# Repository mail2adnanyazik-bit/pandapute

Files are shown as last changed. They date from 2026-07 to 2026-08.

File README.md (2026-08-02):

# Pandapute - a mini computer built from scratch

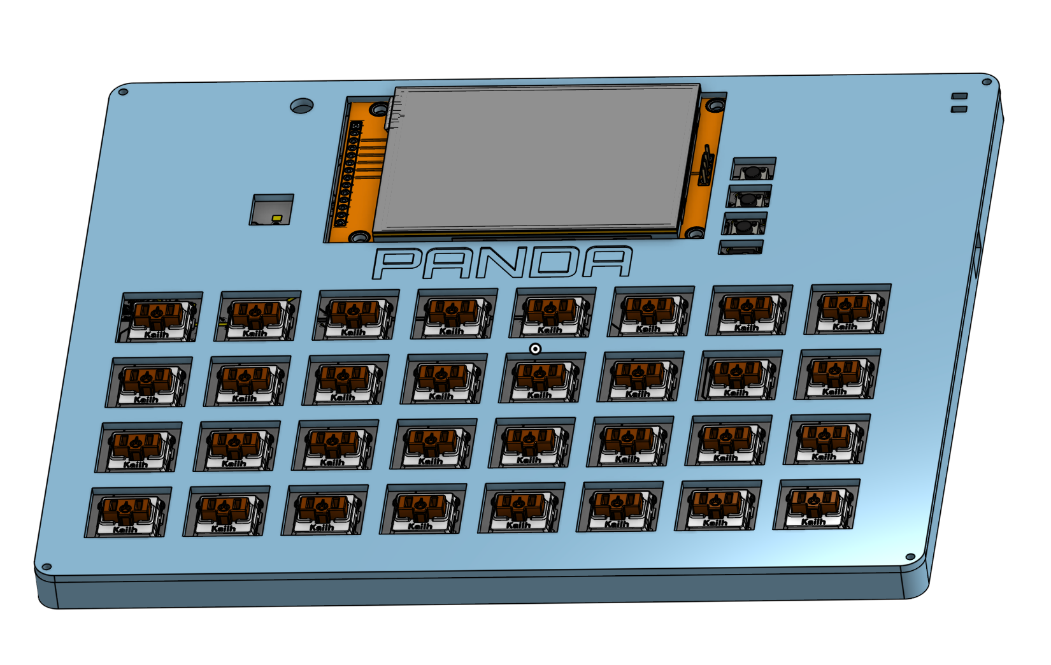
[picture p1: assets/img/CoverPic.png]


Before you keep reading and find out more about my kickass project, first I want to give credit and a massive thanks to @zsharpminor, or Udo - He's my first friend on Hack Club, a reviewer, and all-around great guy who helped me with this project along every step of the way.
This project would not have been possible without him, so <3 to him :D

## The Inspiration

So, one day I was working on my Split Keyboard project at my makespace, and I saw a friend of mine using a cardputer adv (which is a small, portable esp-based computer - see pic), and was curious.
I asked him what it was, and he showed me, and I gotta say, I was skeptical at first, but then I was blown away - I just had one complaint when I saw the thing :
the keyboard. You see, the original cardputer uses this tiny ass 56-key keyboard, which is 1) too many keys in my opinion, and 2) extremely hard to type on.

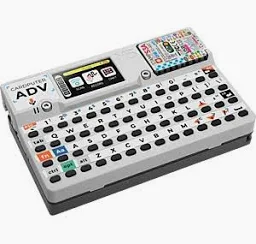
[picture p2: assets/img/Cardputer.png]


So, I decided to make my own, and get funding from Outpost.

## The Features

So, the Pandapute features every single feature the Cardputer has + more !

It has :

- The best ESP32 chip that has wifi and bluetooth capabilities (ESP32-S3-WROOM-1-N16R8)
- an actual **extremely** low profile, compact, built in mechanical 32-key keyboard
- an Audio Jack
- A LiPo battery that will last ages
- a built in speaker
- a microphone
- exposed I2C, GPIO, Power, etc. Pins so you can connect external modules or breakout boards, like a secondary display
- A USB-C port for **both** flashing **and** charging
- a tilt sensor (to do cool stuff)
- a 2.8" display (around twice as big as the cardputer)

## The Build

The Cardputer is built from scratch by me, Panda

It features an entirely custom

### Schematic

#### Power

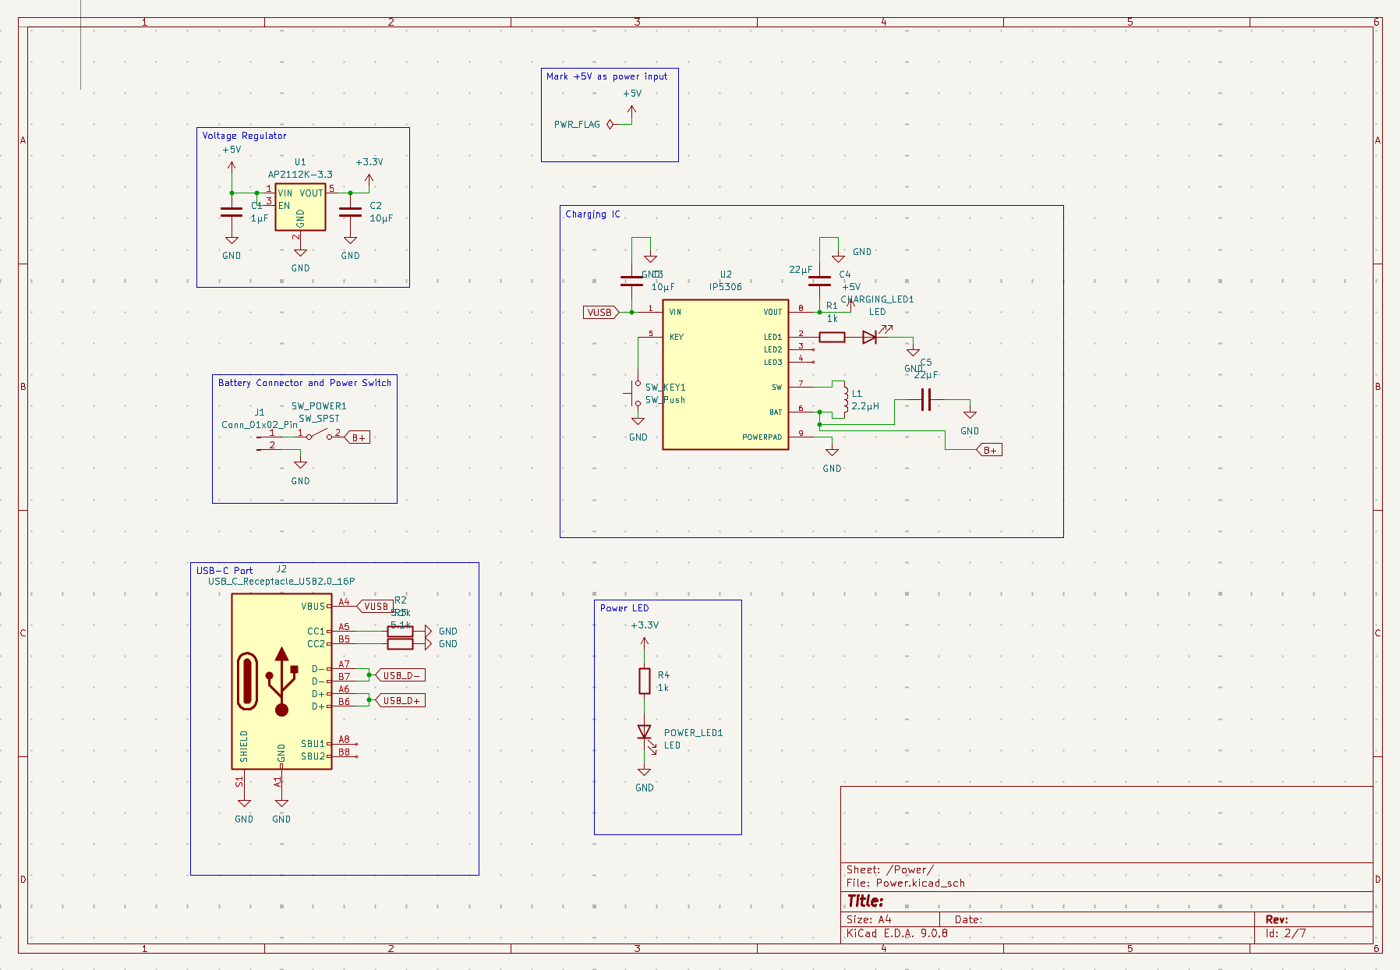
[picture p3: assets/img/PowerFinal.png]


#### ESP



#### Audio

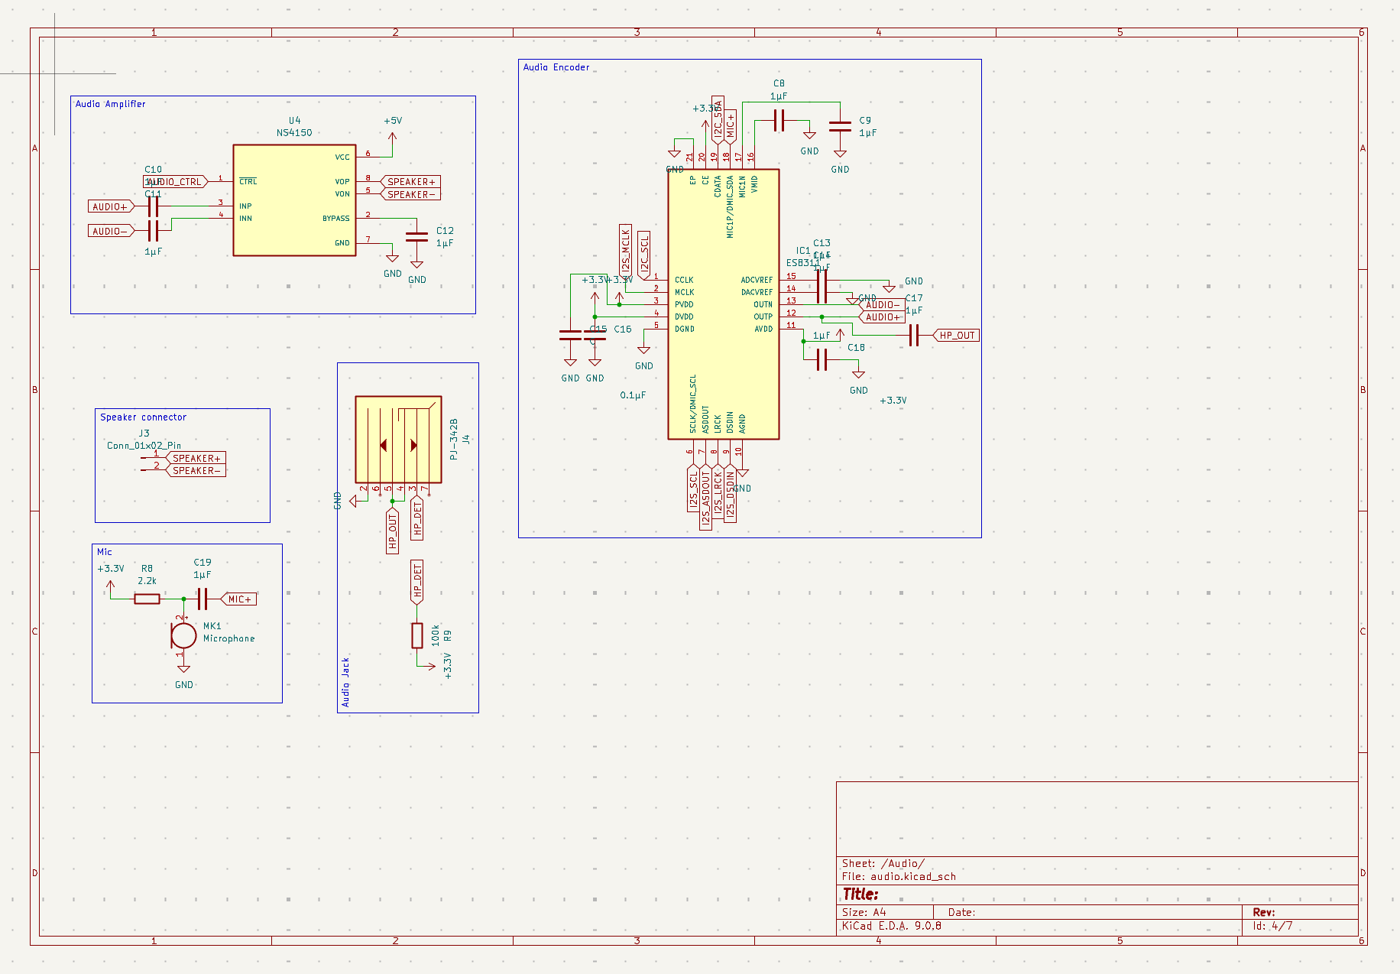
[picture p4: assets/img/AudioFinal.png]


#### Display

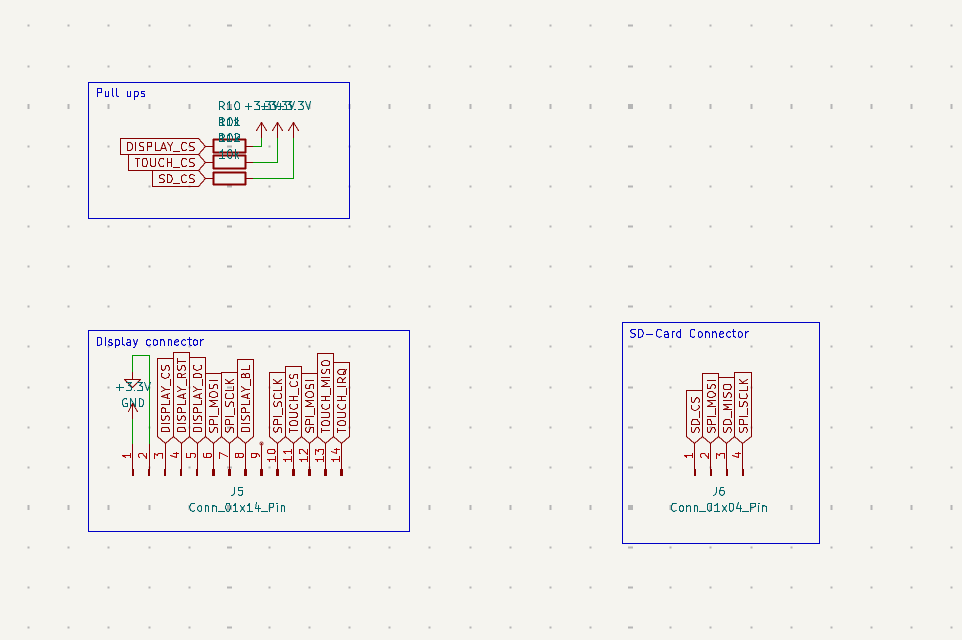
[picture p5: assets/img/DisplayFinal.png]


#### Keyboard

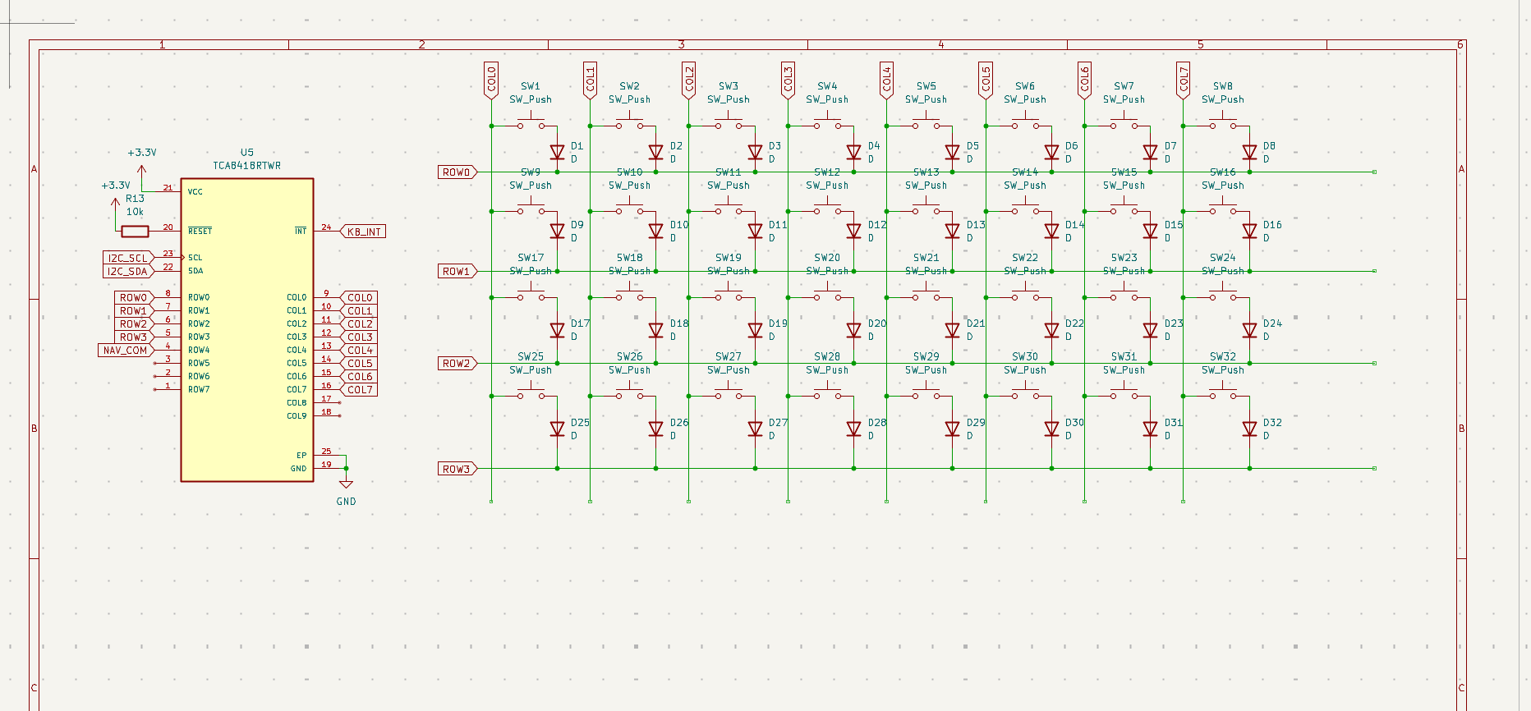
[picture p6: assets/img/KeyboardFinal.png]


#### Peripherals

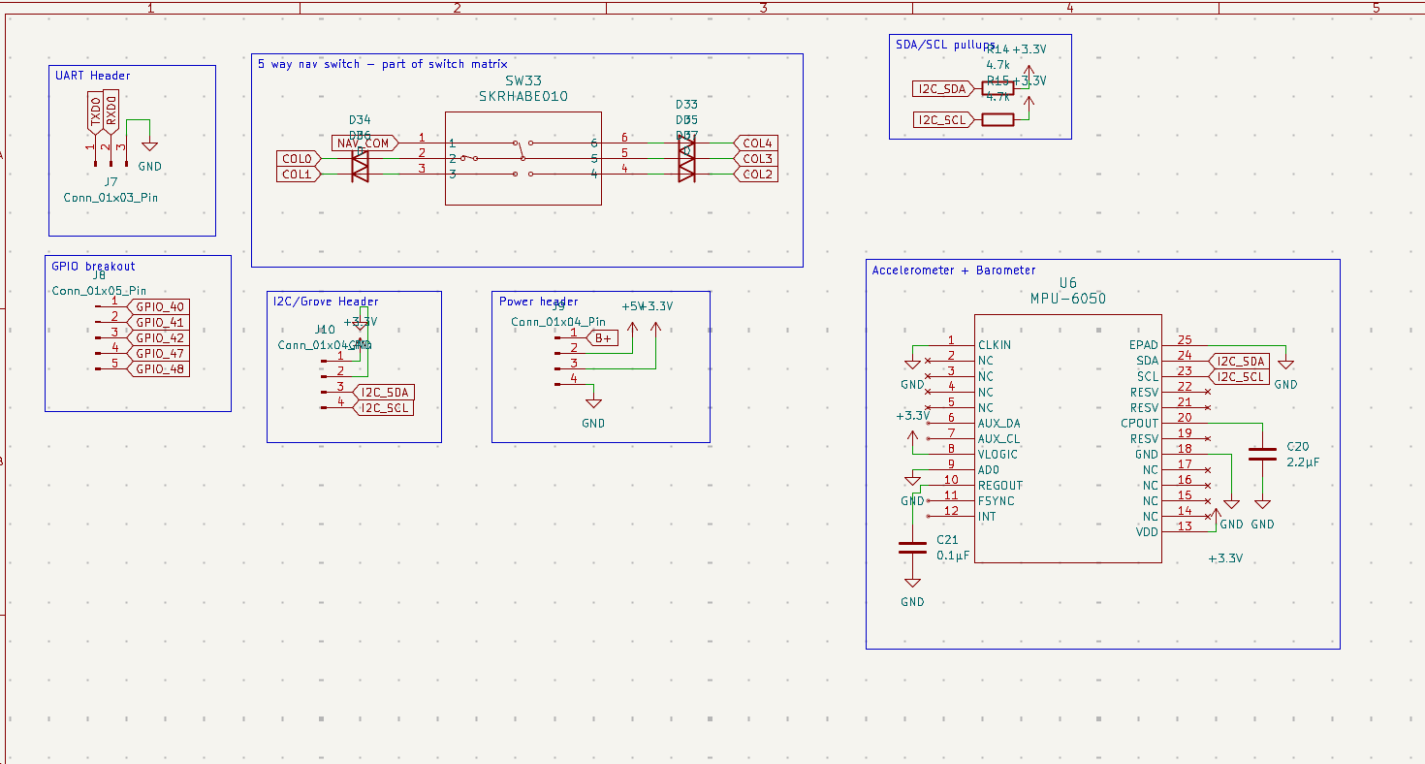
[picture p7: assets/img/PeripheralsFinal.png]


and

### PCB

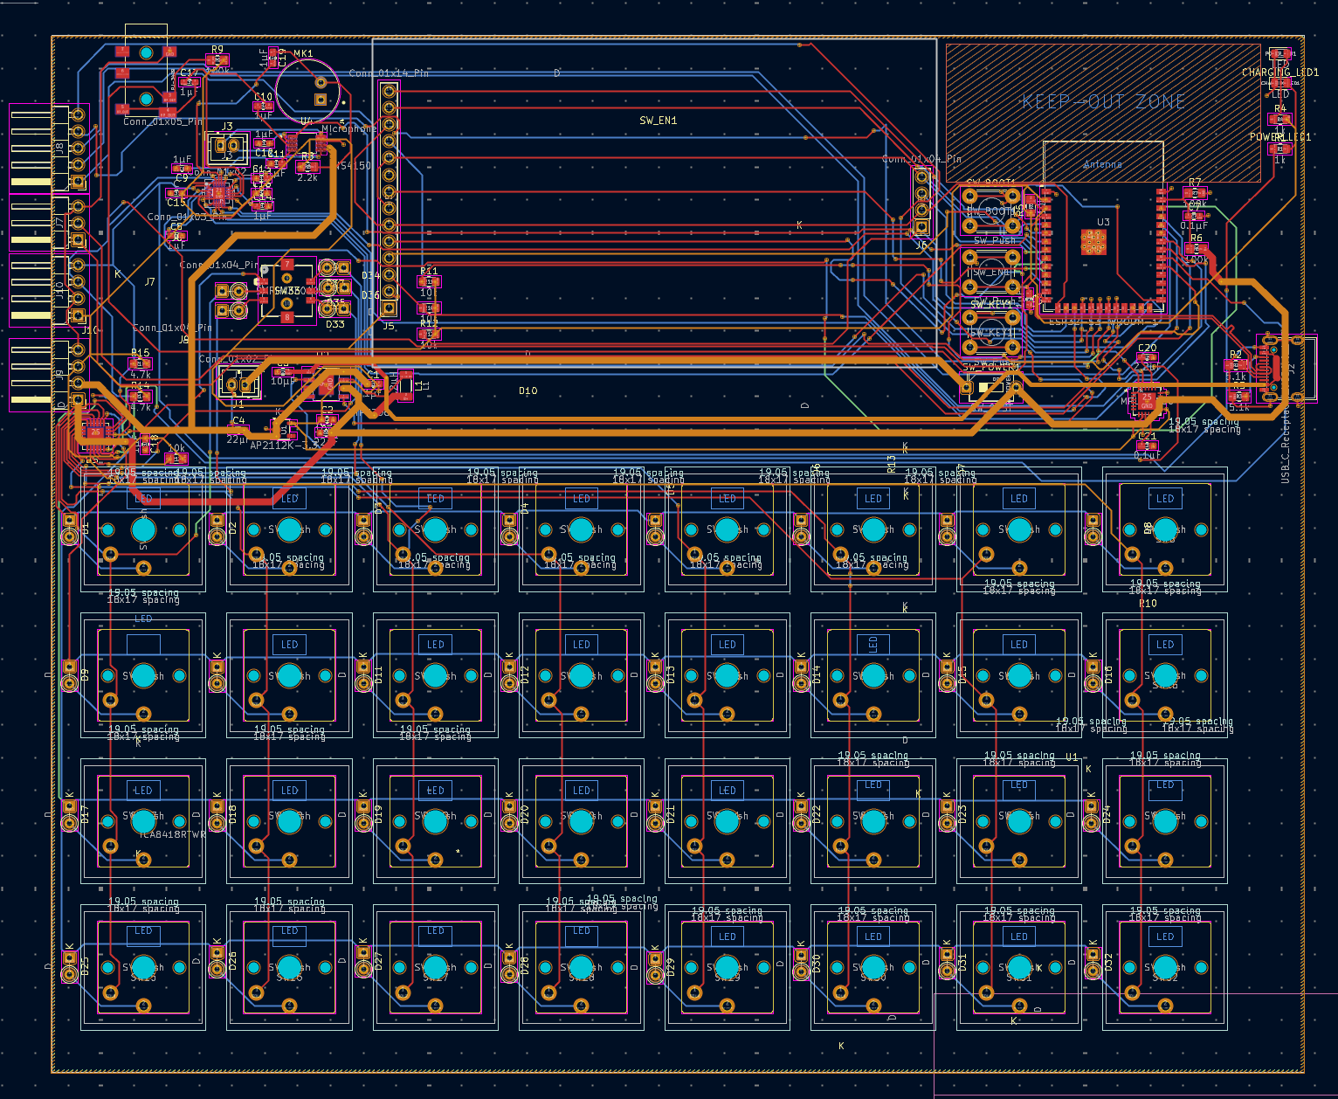
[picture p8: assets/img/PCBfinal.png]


to visualize how this will look in real life, here are a few pics ! I only added the important components that you'll actually see, not the encoder chips and stuff :

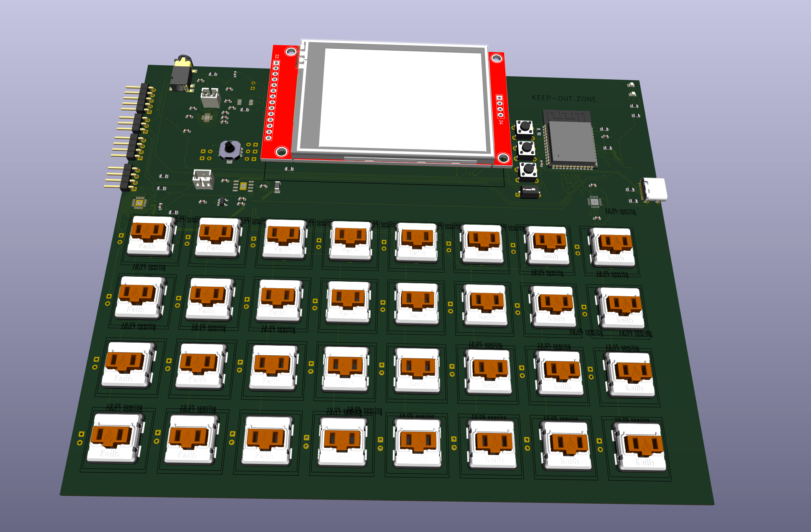
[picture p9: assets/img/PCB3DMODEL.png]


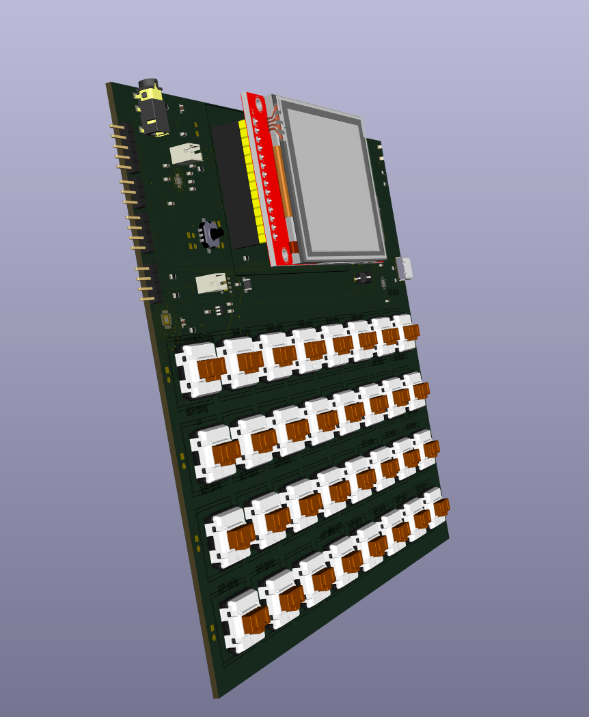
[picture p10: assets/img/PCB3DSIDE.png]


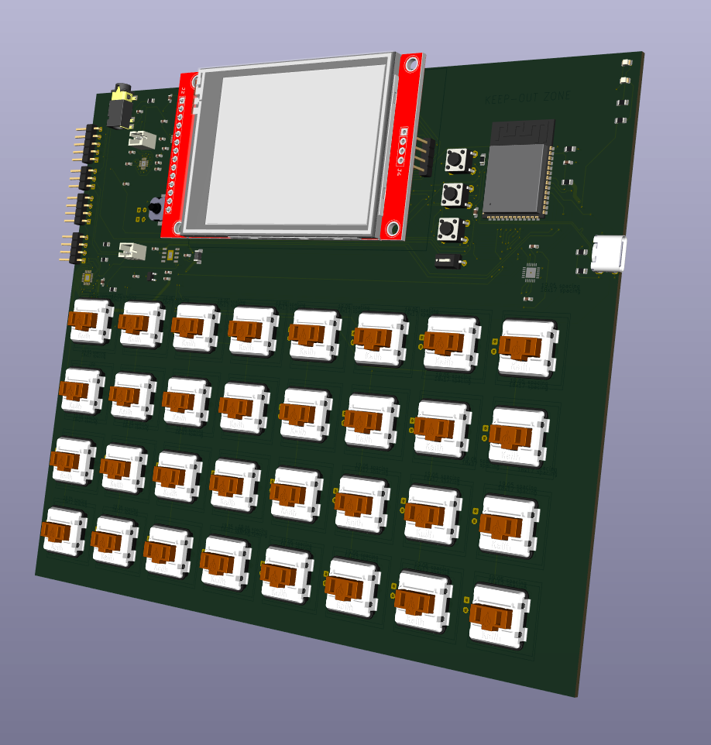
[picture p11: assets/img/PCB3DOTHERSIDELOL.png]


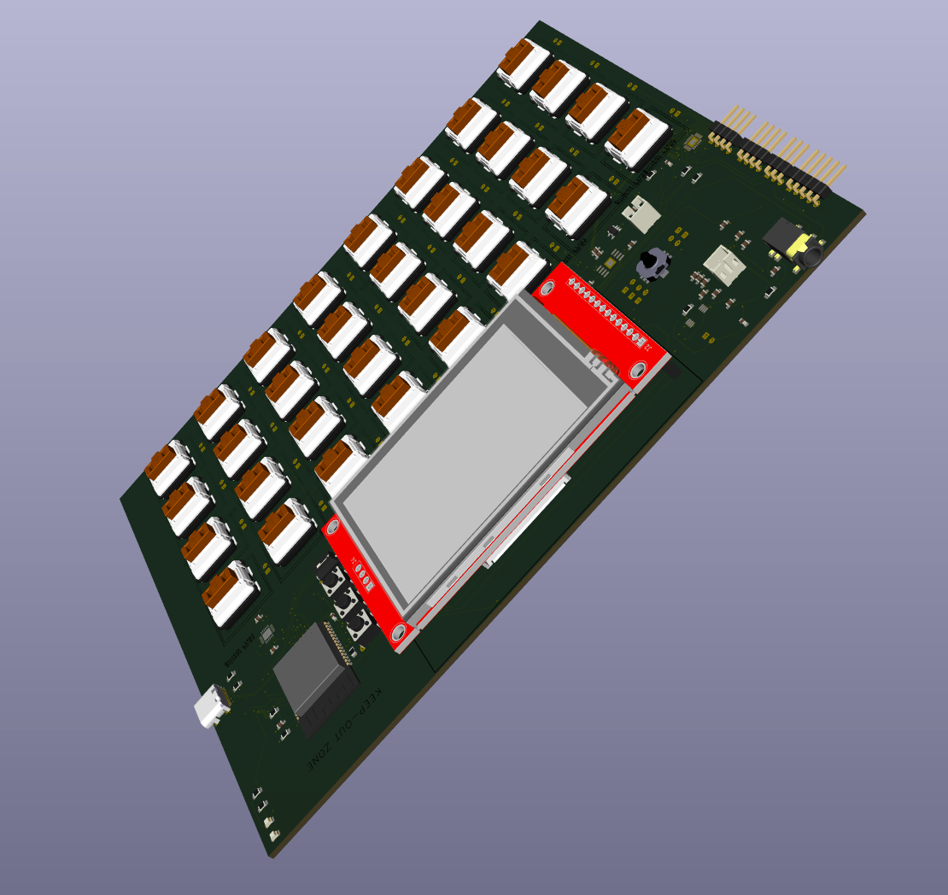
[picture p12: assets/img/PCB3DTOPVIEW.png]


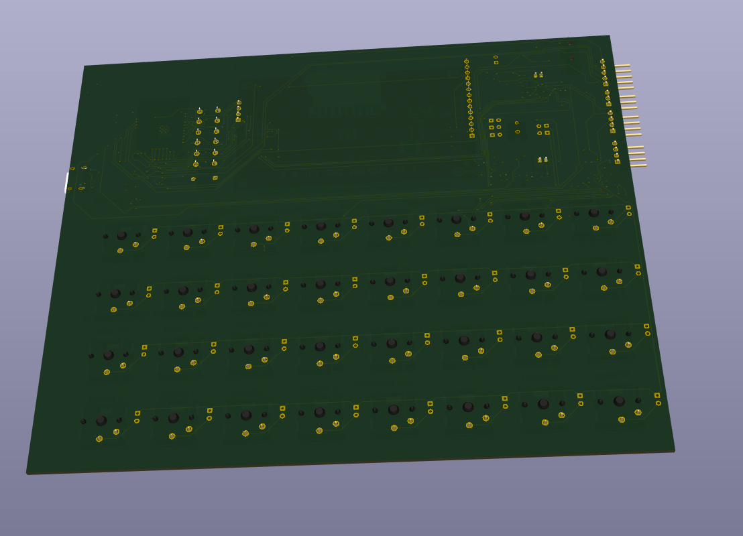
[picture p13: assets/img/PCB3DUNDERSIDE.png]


Now you're probably wondering, will you just carry a PCB around ? OF COURSE NOT. But you know what I'm also not gonna do ?
Put it in some lame ass 3d printed case. That would be boring, inaccurate, and wouldn't feel good in my hands. So ... what's my solution for the

### Case ?

You see, instead of the usual 3d printed stuff, I've decided I'm going to use the full potential of my makespace and make
a custom wood case with a nice finish and accurate measurements after ordering the components, using my local wood workshop.

Another reason for the wood case is inaccuracy - what I mean by that is that some of my components have rather inaccurate measurements - the measurements I have currently on the PCB are only approximations for some components, for example my display :
Since there isn't a prebuilt footprint for this, I had to make my own version which is based on a user-made 3d model approximation of the same component - the downside of this is that it's not accurate.
For the PCB this is rather easy to fix - just order the components first and _then_ adjust the PCB after measuring the components with a digital caliper !

As to how the case will be assembled - it will be made up of 2 parts - One bottom shell which holds the PCB and has holes for the audio jack, USB-C port, and whatever else sticks out the side, and one Top Plate which has holes that the top components that should be exposed can poke through (screen, switches, keyboard, etc.)

To visualize how the entire thing will look, I made a CAD after @zsharpminor (my first friend on Hack Club, was a great help, if you're reading this tysm ! ) said it would be helpful for polish

I first made a model of the Bottom Shell :

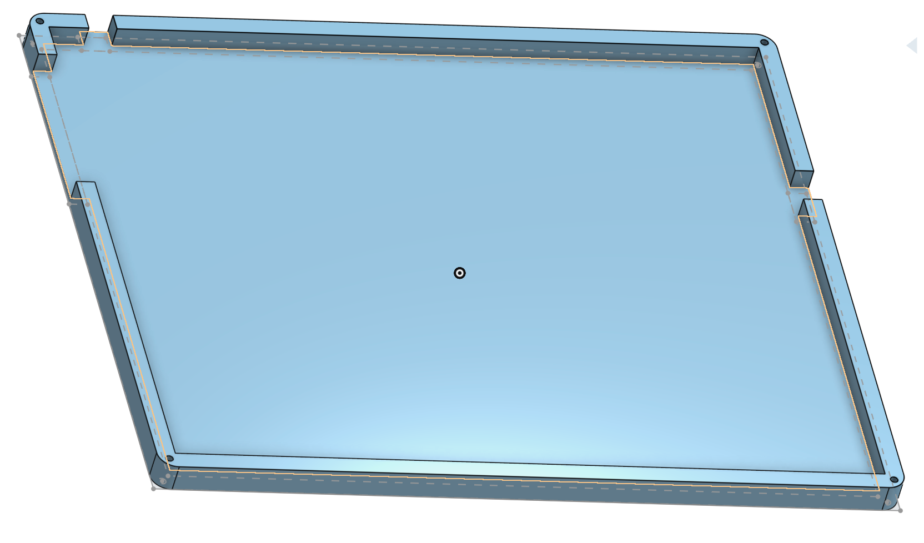
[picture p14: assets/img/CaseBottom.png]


Then of the Top part (with cool Panda logo, also thanks to zsharp's feedback - again, tysm for putting up with me zsharp !)

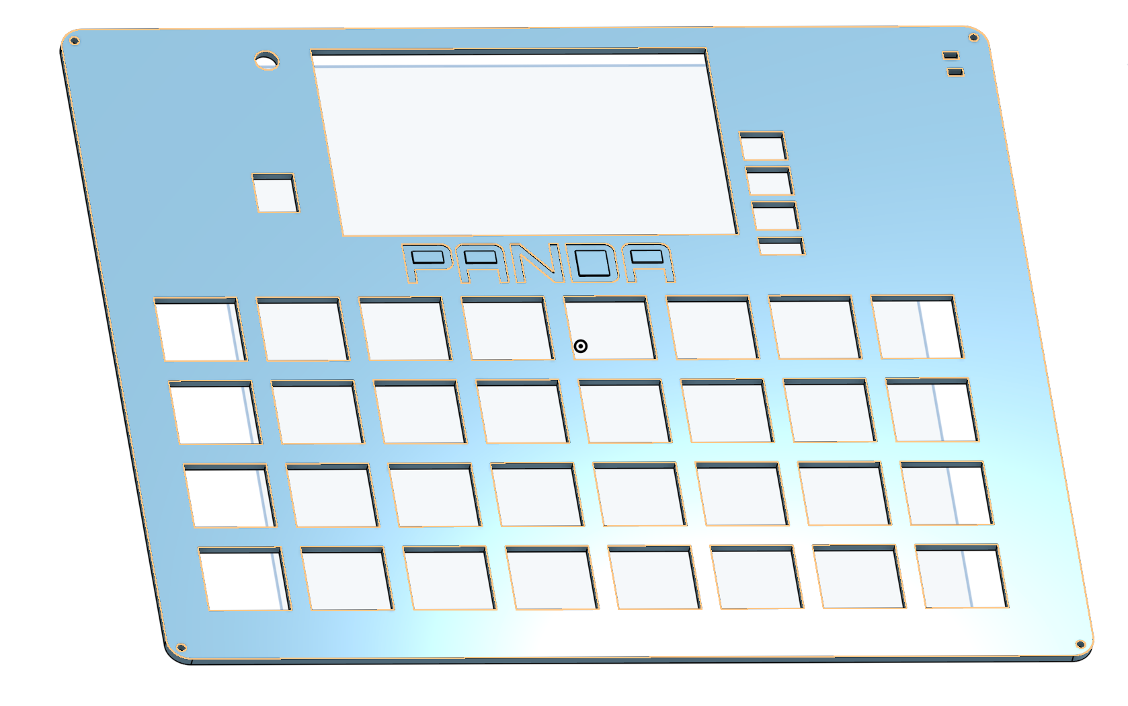
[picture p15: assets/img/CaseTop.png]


After that for visualization purposes I made an Assembly to show how it will look in the end :

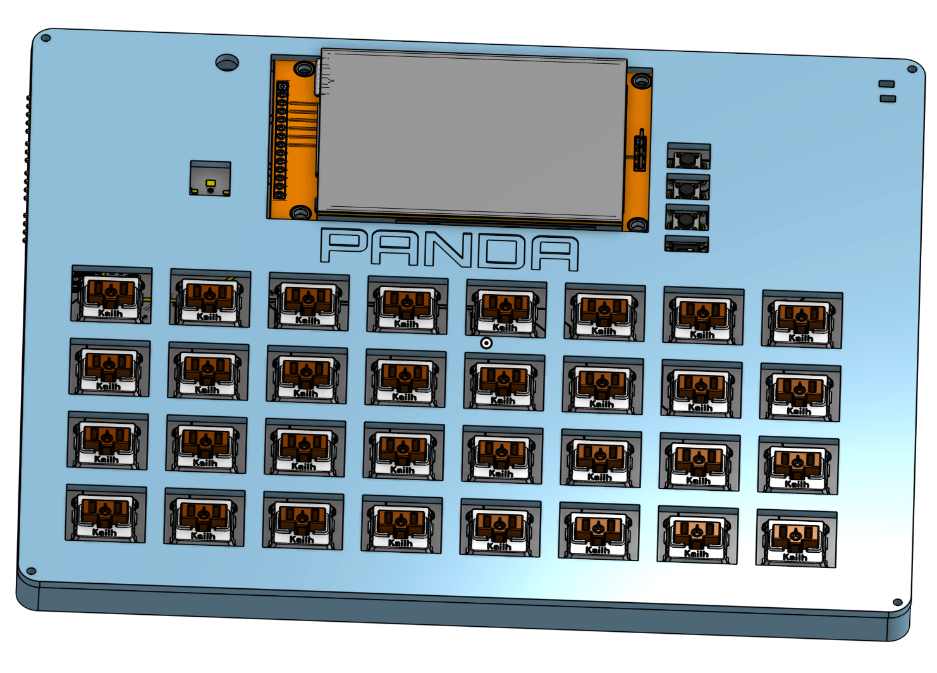
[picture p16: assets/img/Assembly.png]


If you want a better more interactive look at this case and how it's built, check out the Onshape document where I made it !

https://cad.onshape.com/documents/acd94843717f517182d6e668/w/23be4fdb216877c251d3e9a3/e/5f36188dd017400931f1858c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

## Firmware

The firmware is a full OS-like environment, not just a bunch of drivers. It runs on the Arduino framework with PlatformIO and gives you a desktop UI, terminal, text editor, file manager, and USB HID keyboard mode.

```
firmware/
├── platformio.ini               # dev + release builds (TFT_eSPI, SdFat)
├── include/
│   ├── config.h                 # all pin definitions
│   ├── kernel.h                 # OS kernel — app management, status bar
│   └── apps.h                   # app function declarations
└── src/
    ├── main.cpp                 # boots hardware + OS, main event loop
    ├── kernel.cpp               # app switching, status bar, event routing
    ├── apps/
    │   ├── desktop.cpp          # home screen — app grid launcher
    │   ├── terminal.cpp         # shell with commands (help, clear, echo, bat, reboot)
    │   ├── editor.cpp           # text editor — cursor, insert/delete, Ln/Col status
    │   ├── files.cpp            # SD card file browser
    │   ├── settings.cpp         # brightness, volume, USB mode toggles
    │   ├── piano.cpp            # keyboard piano — keys 1-8 play notes, octave shift
    │   ├── mic.cpp              # mic level visualizer — real-time bar graph
    │   └── tilt.cpp             # MPU6050 orientation — circle + dot + accel/gyro values
    ├── keyboard/                # 4×8 matrix scanner, debounce, HID keymap
    ├── display/                 # TFT_eSPI wrapper
    ├── audio/                   # I²S output + ES8311 codec + mic input
    ├── touch/                   # XPT2046 SPI touch with calibration
    ├── power/                   # IP5306 battery manager + ADC fallback
    ├── sd_card/                 # SdFat wrapper
    ├── usb_hid/                 # USB HID keyboard — plug in and type
    └── mpu/                     # MPU6050 accelerometer + gyroscope driver
```

#### OS Architecture

The **kernel** manages 8 apps and a persistent status bar. Every keypress is routed to the currently focused app. The loop runs at ~100 Hz:

1. **Keyboard** — matrix scan → debounce → HID keycode lookup
2. **USB HID** — if connected to a computer, sends the same keystrokes
3. **App** — keypress fed to current app's `on_key()` handler
4. **Touch** — polls XPT2046 for touch position
5. **Battery** — reads IP5306 every 10s, shows in status bar
6. **Status bar** — redrawn every 200ms with app name + battery %
7. **Sensors** — MPU6050 and microphone polled by their respective apps

#### Apps

| App | Icon | What it does |
| --- | ---- | --- |
| Desktop  | ~ | Grid launcher, arrow keys to navigate, Enter to launch, ESC back |
| Terminal | > | Shell with `help, clear, echo, bat, apps, reboot` |
| Editor | E | Notepad with cursor movement, insert/delete, modified indicator  |
| Files | F | SD card directory listing |
| Settings | S | Brightness slider (PWM), volume (I²C codec), USB mode toggles |
| Piano | P | 8-key piano (keys 1-8), UP/DN change octave, visual key press |
| Mic | M | Real-time microphone level bar graph, record/pause toggle |
| Tilt | T | 3D orientation circle with dot, live accelerometer/gyro values |

Pressing **ESC** from any app returns to the Desktop.

#### USB HID

When connected to a computer via USB-C with `-DARDUINO_USB_MODE=1` and `-DARDUINO_USB_CDC_ON_BOOT=1`, the Pandapute shows up as a standard USB keyboard. Everything you type on the mechanical keyboard goes straight to the computer. Modifier keys (Shift, Ctrl, Alt) work too.

#### Building

```bash
cd firmware
pio run -e esp32-s3-dev
pio run -e esp32-s3-dev -t upload
pio device monitor -b 115200
```

Display pins are set in `platformio.ini` via `build_flags`. Touch and SD pins are in `config.h`.

#### Keymap

The keymap in `keyboard/keymap.h` uses standard USB HID keycodes (0x04–0xE7). Modify the `KEYMAP[4][8]` array to match your physical key placement. There are placeholder arrays for `KEYMAP_FN` and `KEYMAP_SYM` layers if you want dual-layer action later.

#### config.h

Single file with every pin, I²C address, and system constant. Change the PCB pinout → edit one file.

### BOM

| # | Qty | Part | Price (€)  | Notes |
| --- | --- | --- | --- | --- |
| 1 | 1 | ESP32-S3-WROOM-1 N16 | 6.07 | Microcontroller |
| 2 | 1 | IP5306 | 1.15 | Charging IC |
| 3 | 1 | ES8311 | 3.79 | Audio encoder IC |
| 4 | 1 | TCA8418RTWR | 1.85 | Switch matrix scanning IC |
| 5 | 3 | Tactile switches | 9.19 | Power/Boot/etc. switch |
| 6 | 1 | CMA-4544PF-W | 8.29 | Microphone |
| 7 | 1 | 2000 mAh 3.7V LiPo Battery | 10.79 | Battery |
| 8 | 1 | ILI9341 | 6.19 | Display |
| 9 | 32  | Kailh extreme low profile keycaps | 39.79 | Keycaps |
| 10  | 1 | USB-C 2.0 receptacle 16 pin | 2.09 | USB-C port |
| 11  | 32  | IN4148 | 1.05 | Diode |
| 12  | 32  | Kailh choc v1 brown switches | 26.79 | Keyboard switches |
| 13  | 2 | Blue and green LEDs | 3.00 | LEDs |
| 14  | / | Resistors from 1 - 100k | 4.00 | Resistor kit |
| 15  | 1 | 12 V SPST Switch | 2.09 | Switch for battery |
| 16  | 1 | SKRHABE010 | 2.59 | 5 way nav switch |
| 17  | 1 | JST connector kit | 3.00 | Connector |
| 18  | 1 | PJ-342B | 2.69 | 3mm Audio Jack |
| 19  | 1 | Inductor kit | 5.29 | Inductors |
| 20  | 1 | MPU6050 | 4.79 | Tilt sensor |
| 21  | 1 | 4 Ohm 3 Watt stereo speaker | 1.79 | Speaker |
| 22  | 1 | 32GB SD Card | 8.39 | Storage |
| | 1 | **PCB** | **140.00** | 191×158mm 4-layer |
| | 1 | **Shipping** | **40.00**  | |
| | | **Total** | **334.67** | |
| | | **Total (USD)** | **379.89** | |

## Why X Tier ?

Although this project was initially supposed to be S-Tier and _much_ more simple than its current version, the idea really
grew on me, and I kept having more and more cool ideas for features I could add, and for some reason I _really_ wanted to outdo the cardputer.
So I put in the effort, watched literal days of videos on differential pairs, PCB design, and looked through countless datasheets just to make this project the best it could possibly be.
It evolved into a complex, extremely cool learning experience and project, not just for me, but for every person at my makespace and on slack who spent hours with me, showing me
what I did wrong (it was a lot), what could be improved (also a lot), and what I did well - A great thanks to all of those people too !

Also, to any reviewers - I hope this project makes the cut for X Tier, and if not, I'll make sure to put in the work to somehow get it there, as it could never survive
on just S Tier.

All in all, I'm extremely happy with what I learned, how much time I put in to this, and how many people contributed to this project.

I couldn't be more proud

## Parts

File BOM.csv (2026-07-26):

Name | Type | Quantity | Total price in Euro | Link
ESP32-S3-WROOM-1 N16 | Microcontroller | 1 | 6.07 | https://de.aliexpress.com/item/1005006191820262.html?mp=1
IP5306 | Charging IC | 1 | 1.15 | https://de.aliexpress.com/item/1005012267114327.html?mp=1
ES8311 | Audio encoder IC | 1 | 3.79 | https://de.aliexpress.com/item/1005011809463921.html?mp=1
TCA8418RTWR | Switch matrix scanning IC | 1 | 1.85 | https://de.aliexpress.com/item/1005008143876123.html?mp=1
Tactile switches | Power/Boot/etc. switch | 3 | 9.19 | https://de.aliexpress.com/item/32865593815.html?mp=1
CMA-4544PF-W | Microphone | 1 | 8.29 | https://de.aliexpress.com/item/1005009251734269.html?mp=1
2000 mAh 3.7V LiPo Battery | Battery | 1 | 10.79 | https://de.aliexpress.com/item/1005005984841109.html?mp=1
ILI9341 | Display | 1 | 6.19 | https://de.aliexpress.com/item/33015586094.html?mp=1
Kailh extreme low profile keycaps | Keycaps | 32 | 39.79 | https://de.aliexpress.com/item/33015586094.html?mp=1
USB-C 2.0 receptacle 16 pin | USB-C port | 1 | 2.09 | https://de.aliexpress.com/item/1005006353547160.html?mp=1
IN4148 | Diode | 32 | 1.05 | https://de.aliexpress.com/item/1005006208000285.html?mp=1
Kailh choc v1 brown switches | Keyboard switches | 32 | 26.79 | https://de.aliexpress.com/item/1005011812362132.html?mp=1
Blue and green LEDs | LEDs | 2 | 3 | https://de.aliexpress.com/item/1005006781648580.html?mp=1
Resistors from 1 - 100k | Resistor kit | / | 4 | https://de.aliexpress.com/item/1005006781648580.html?mp=1
12 V SPST Switch | Switch for battery | 1 | 2.09 | https://de.aliexpress.com/item/1005006393976008.html?mp=1
SKRHABE010 | 5 way nav switch | 1 | 2.59 | https://de.aliexpress.com/item/32998104973.html?mp=1
JST connector kit | Connector | 1 | 3 | https://de.aliexpress.com/item/1005007389108799.html?mp=1
PJ-342B | 3mm Audio Jack | 1 | 2.69 | https://de.aliexpress.com/item/1005007847480112.html?mp=1
Inductor kit | Inductors | 1 | 5.29 | https://de.aliexpress.com/item/1005006066709165.html?mp=1
MPU6050 | Tilt sensor | 1 | 4.79 | https://de.aliexpress.com/item/1005012615808391.html?mp=1
4 Ohm 3 Watt stereo speaker | Speaker | 1 | 1.79 | https://de.aliexpress.com/item/1005008626624201.html?mp=1
32GB SD Card | Storage | 1 | 8.39 | https://de.aliexpress.com/item/1005007498167692.html?curPageLogUid=KxeuYGSrQVMa
191 x 158 mm 4 Layer PCB | PCB | 1 | 140 | pcbway.com
Shipping | Shipping | 1 | 40
Total in Euros | 334.67
Converted Total in Dollars | 379.89

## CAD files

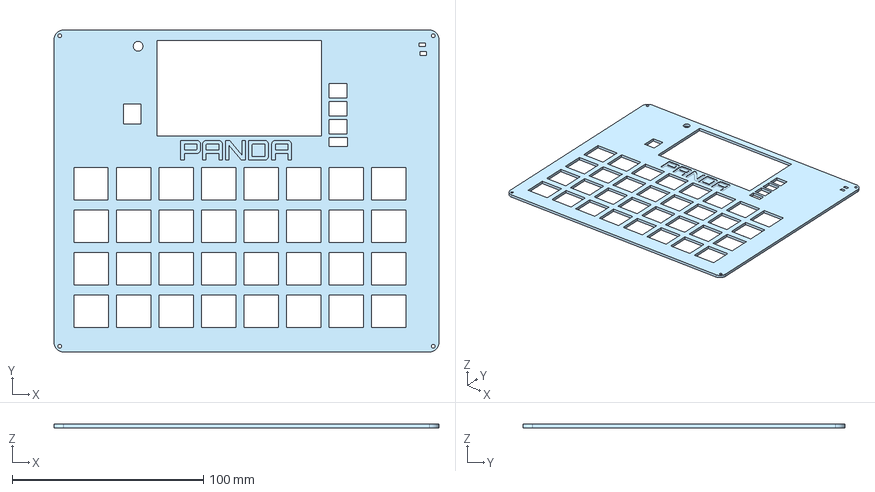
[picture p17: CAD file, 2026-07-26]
CAD/Case/CaseTop.step
201.4 x 168.4 x 2.00 mm

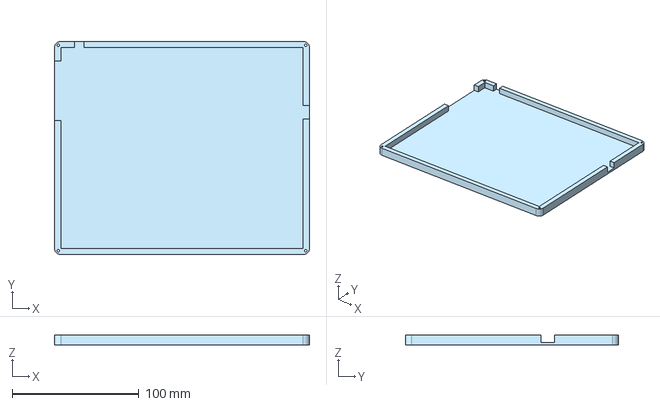
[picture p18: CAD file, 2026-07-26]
CAD/Case/CaseBottom.step
201.4 x 168.4 x 8.00 mm

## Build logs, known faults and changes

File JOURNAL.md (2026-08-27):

# Pandapute — Dev Journal

## 2026-07-07 — Session 1: Project Kickoff (~3 hours)

The project started out with me seeing a fellow maker friend using a cardputer, and i thought it was cool - but then i tried using it myself,
and the tiny keyboard drove me crazy and the screen was so small i needed glasses - not ideal. Since i wanted to build a Cyberdeck anyway but was laxking experience,
i thought i would try and make one from scratch to get some experience with this stuff, and i can get a grant from outpost.

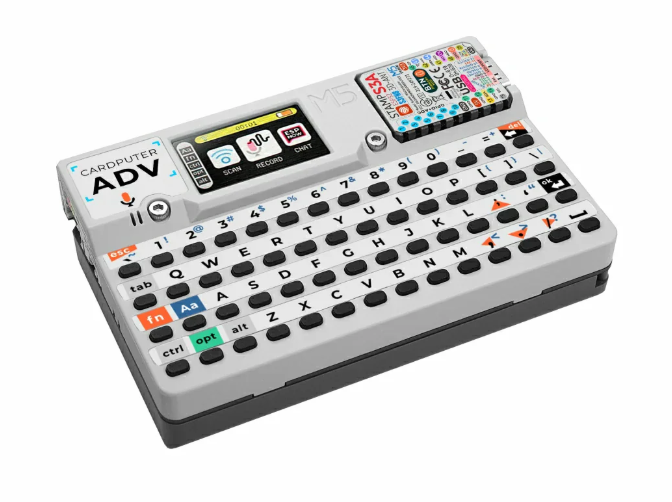
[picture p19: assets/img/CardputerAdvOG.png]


Started out thinking "how hard can it be to build a Cardputer clone?" lol.

Went back and forth on where to buy stuff. Reichelt, Mouser, Amazon, Keycapsss, AliExpress — none of them have everything. Finally realized I should just design the PCB first and let JLCPCB/PCBWay assemble whatever they can, then I only buy the leftovers myself (switches, battery, display, speaker, keyboard stuff).

The plan: **everything on a custom PCB, bare components, no dev boards.** Took a while to get that through my head — kept getting suggested dev boards with displays attached. No. From scratch.

Spent way too long on AliExpress browsing parts. Added ESP32-S3-WROOM-1-N16R8 for €8.59, AMS1117 for pennies, a battery — then realized shipping was gonna kill me if I buy everything separate. So fine, JLCPCB will source the ICs, I'll just get the mechanical stuff myself.

### What I want this thing to have

- Bigger display than the Cardputer (2.8" instead of 1.14")
- Real mechanical Kailh Choc switches, not the membrane one
- Same audio, IR, IMU, microSD — but better
- USB/BT keyboard mode (that's just firmware, ESP32-S3 handles it)
- Grove port for expansion + a bunch of GPIO headers
- RGB LED because why not
- 2000mAh battery (Cardputer has 1750)

## 2026-07-07 — Session 3: Wiring the Power Section (~4 hours)

I am not familiar with any of this which is why it took long. This session was all about wiring the power section in KiCad — correcting mistakes from the last session, adding missing components, and finally getting a complete power tree on the schematic.

What I wired:

- IP5306: VIN→VUSB, SW→L1→BAT, VOUT→+5V, KEY→SW→GND, POWERPAD→GND, LED1→1k→LED
- AP2112K-3.3: VIN→+5V, EN→+5V, VOUT→+3.3V, GND→GND + decoupling caps
- ESP32-S3: 3V3→+3.3V, GND→GND, BOOT→SW→GND, EN→10k to +3.3V + 1µF to GND + SW→GND
- USB_D-/D+ labels connected to GPIO19/20
- Power switch on battery line
- Battery ADC (100k/100k divider + 0.1µF on GPIO1)
- Power LED (1k + LED on +3.3V)
- All C1–C5 caps placed correctly (10µF on VIN, 22µF on BAT/VOUT, 10µF on regulator I/O)

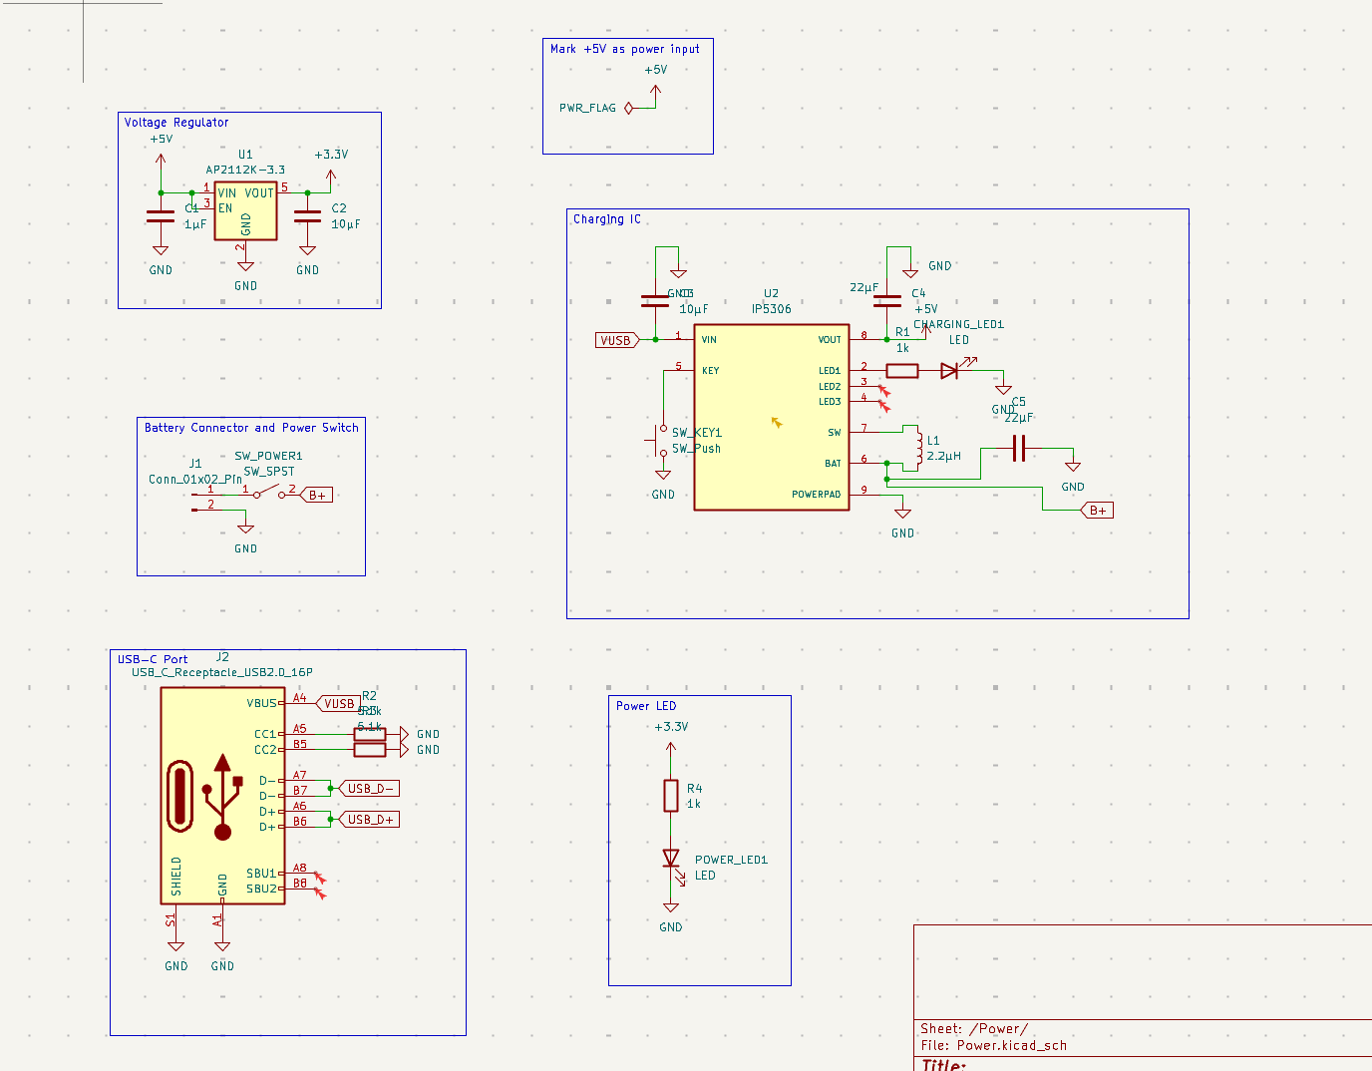
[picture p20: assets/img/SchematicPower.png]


It took literal ages to wire this with soooo much troubleshooting help from gemini, deepseek, opencode and literally everything
Mostly it was the capacitors and resistors and looking at a trillion different stupid datasheets that never have accurate info or a simple
example circuit that pissed me off. also i just realized i would have to wire a differential pair _and_ power lines on the PCB, which _is_ good practice,
but also **exactly** what i was trying to avoid.
anyway, peace out, i think ima work on audio next

## 2026-08-07 - Session 4: Wiring rest of schematic ! (~ 8 hours)

So today i wired the rest of the schematic !

I wired the entire audio sheet - including the mic, speakers, and audio jack : This includes the signal amplifier, the encoder, one stereo speaker, microphone, and also a headphone 3mm audio jack that unfortunately still plays stereo sound.
If you don't no what the difference between stereo and audio sound is, stereo is : stereo is basically built for one type of audio (a single speaker), while stereo is designed for two sides, with both sides playing a bit differently

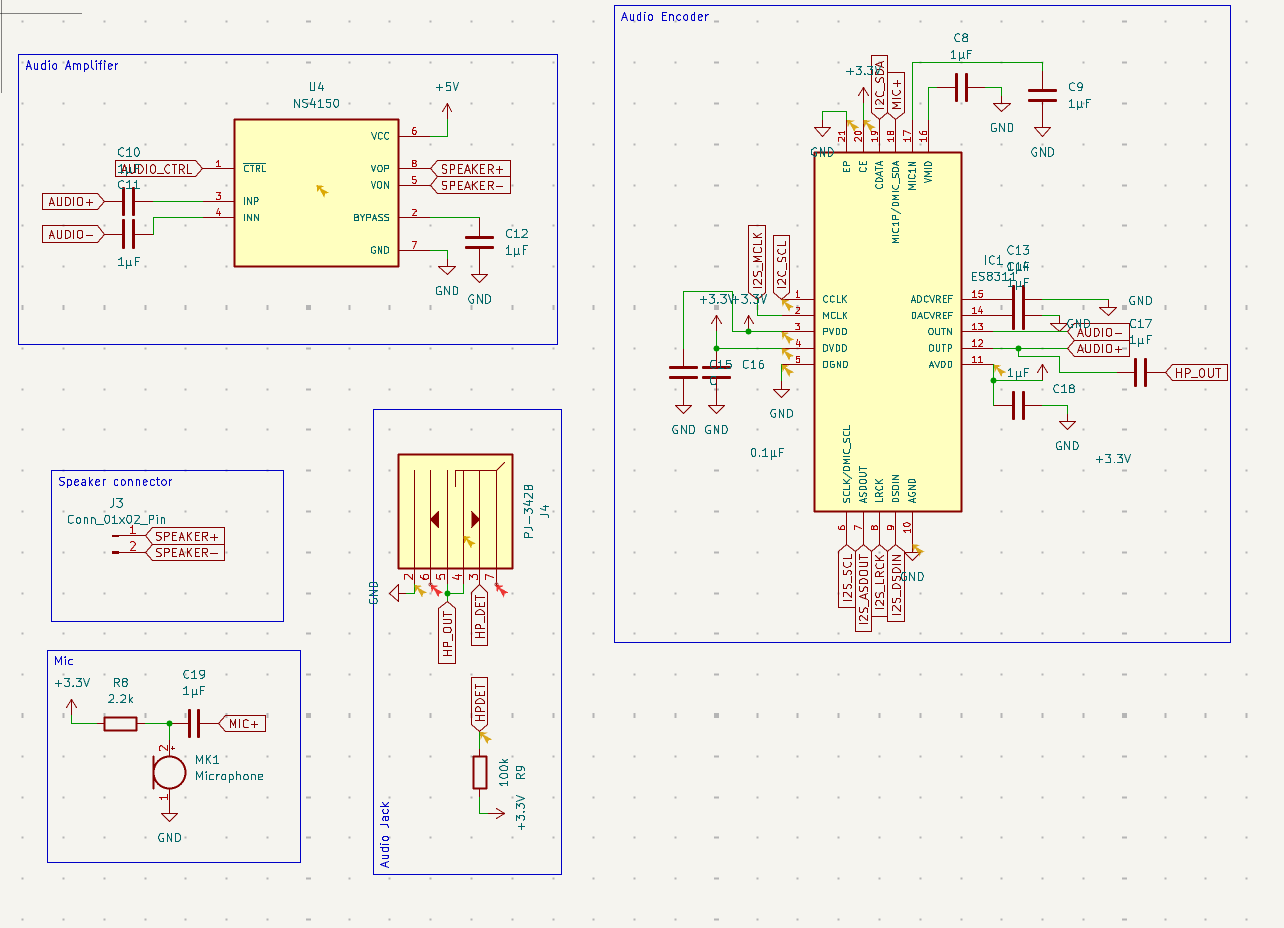
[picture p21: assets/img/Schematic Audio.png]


after that i started wiring the display (which i decided will also have touch) AND SD card slot - because they actually can come together as one module. cause i could'nt find a symbol for this _special_ component, i just used a Pin connector each for both sides.

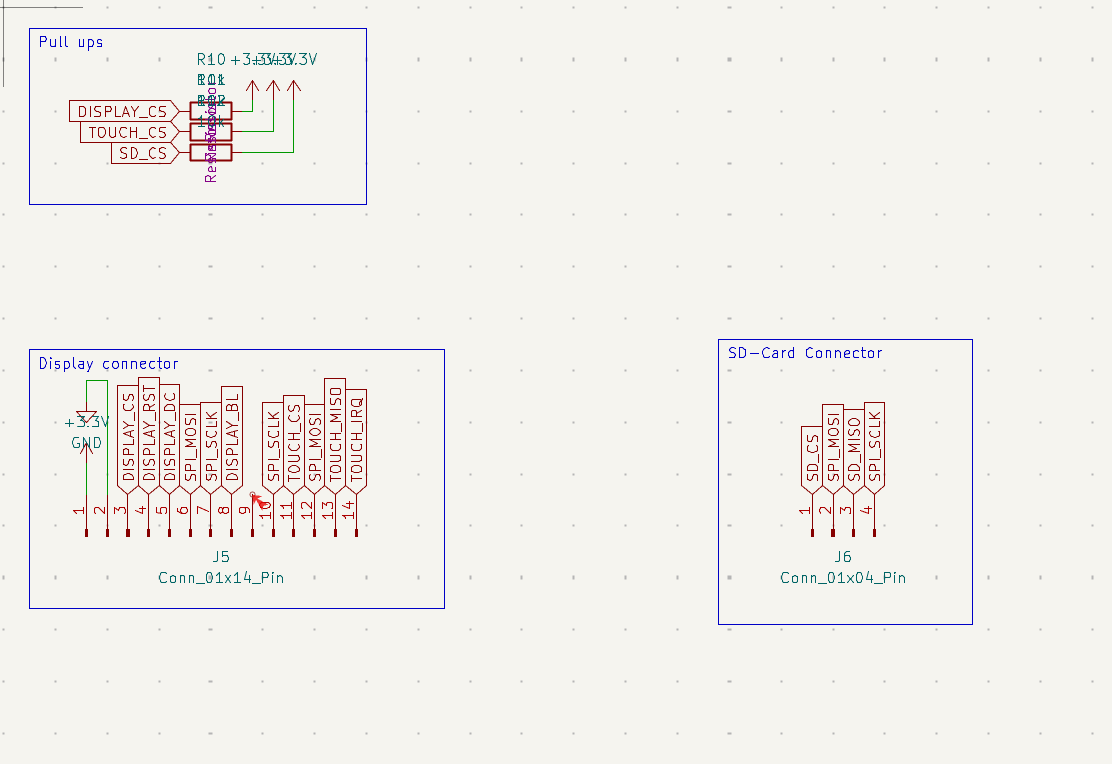
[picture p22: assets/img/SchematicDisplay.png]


Next was the easiest, and probably most satisfying part : The keyboard matrix
The main goal with the Keyboard Matrix was to make it

- as compact and small as possible
- good looking
- low profile
- not too hard to type on
- use a small amount of GPIO pins

in the end, i was able to do all this by using this switch matrix scanner chip called the TCA8418RTWR that takes over all the keyboard matrix scanning :

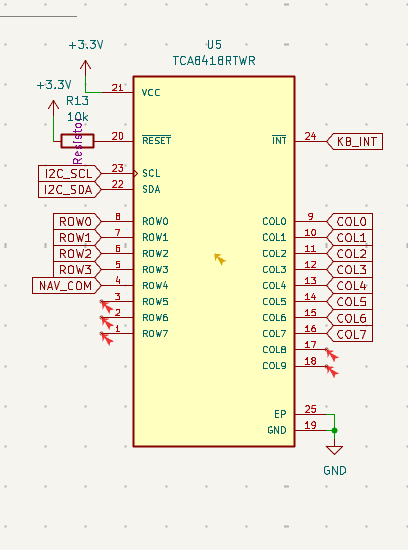
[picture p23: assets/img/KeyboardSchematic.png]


In the End i decided to use a 32-Key layout with 4 rows and 8 coloumns :

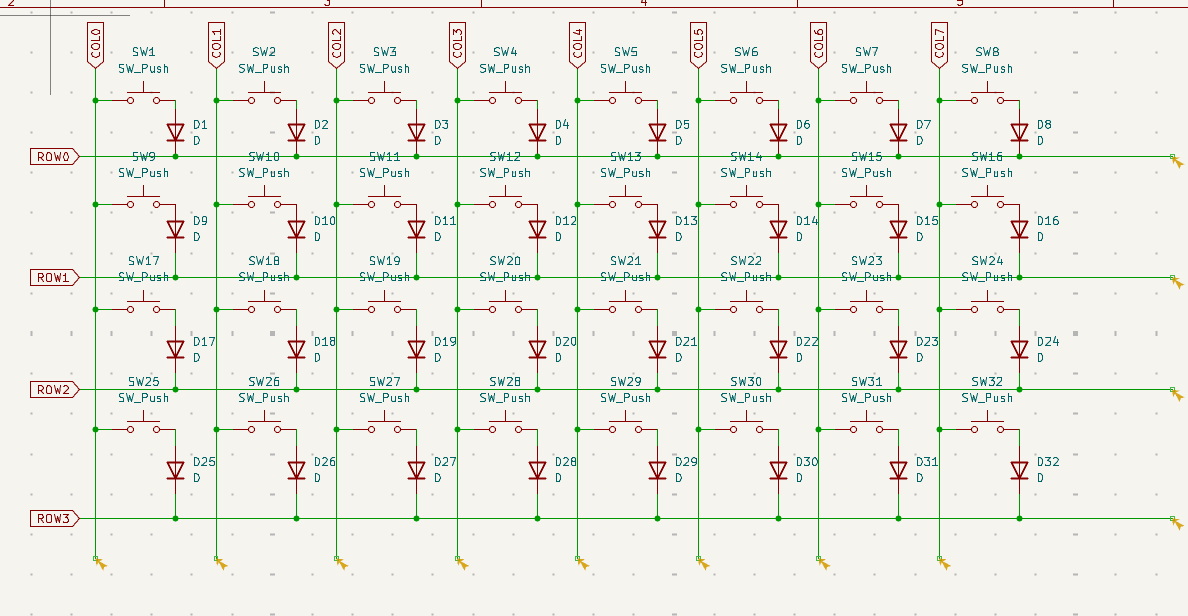
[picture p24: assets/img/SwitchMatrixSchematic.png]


Then came the last (and **most fun**) part - the Peripherals

I decided i wanted some fun stuff like:

- a 5-way nav switch (that is incorporated in the switch matrix to save GPIO pins)

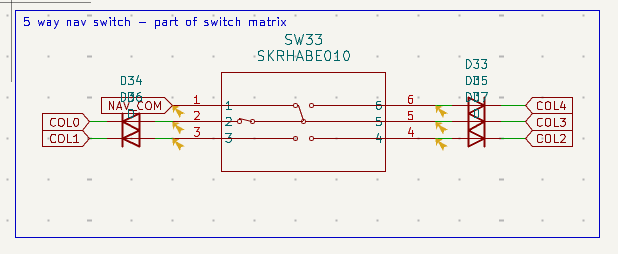
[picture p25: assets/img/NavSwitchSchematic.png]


- a tilt and movement sensor (accelerometer & barometer 2 in 1)



- headers so i can connect other components - i exposed 5 GPIO pins, I2C/Grove for OLEDs and sensors and stuff, and basic Power (3V, 5V, GND, direct battery)

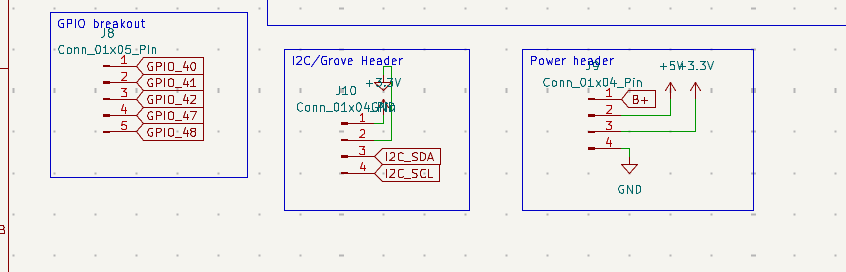
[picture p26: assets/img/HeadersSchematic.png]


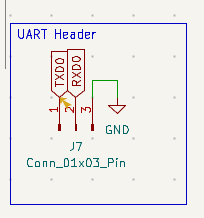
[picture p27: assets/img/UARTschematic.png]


I had wanted to add a rotary encoder, but my GPIO pins ended up occupied and i did not wanna get rid of the GPIO header just for this - also i feel like i uee keyboard shortcuts for everything anyway
next up is footprint assignment and then pcb design, but im rather worried about the footprint for my display + sd module
the problem is, this module has both touch, display, and an sd card, and i cannot find a footprint for that - i could find some that have only diplay and touch, but no SD, or display and SD, but touch unused -
because of this issue, i will just use 2 connectors that are just approx. where the connectors on the module are, and either

1. submit the design files with the approximate measurement, then order the component, buy it, measure where the connector should go, and then adjust my PCB design
   or
2. plug in only one side and use a cable for the other side.

## 2026-09-07 - Session 5 : Footprint assignment and PCB start !

Yeah so i imported, adjusted and assigned every component, and then added everything to the PCB
I then exported everything as a PDF and gave it to an LLM so it could look over it and point out any errors.
I had some minor errors, like some Pads not connected to GND when theyt should have been and a wrong capacitor value, but otherwise
im pretty proud of myself.

Next is to arrange the components on the PCB - also it got recommended to me by the AI
to use a 4 layer PCB, as that lets me dedicate a layer each to GND and POWER - so i have less traces, and no spider nest - cause otherwise EVERY
GND or +3V/+5V connection would need a trace.

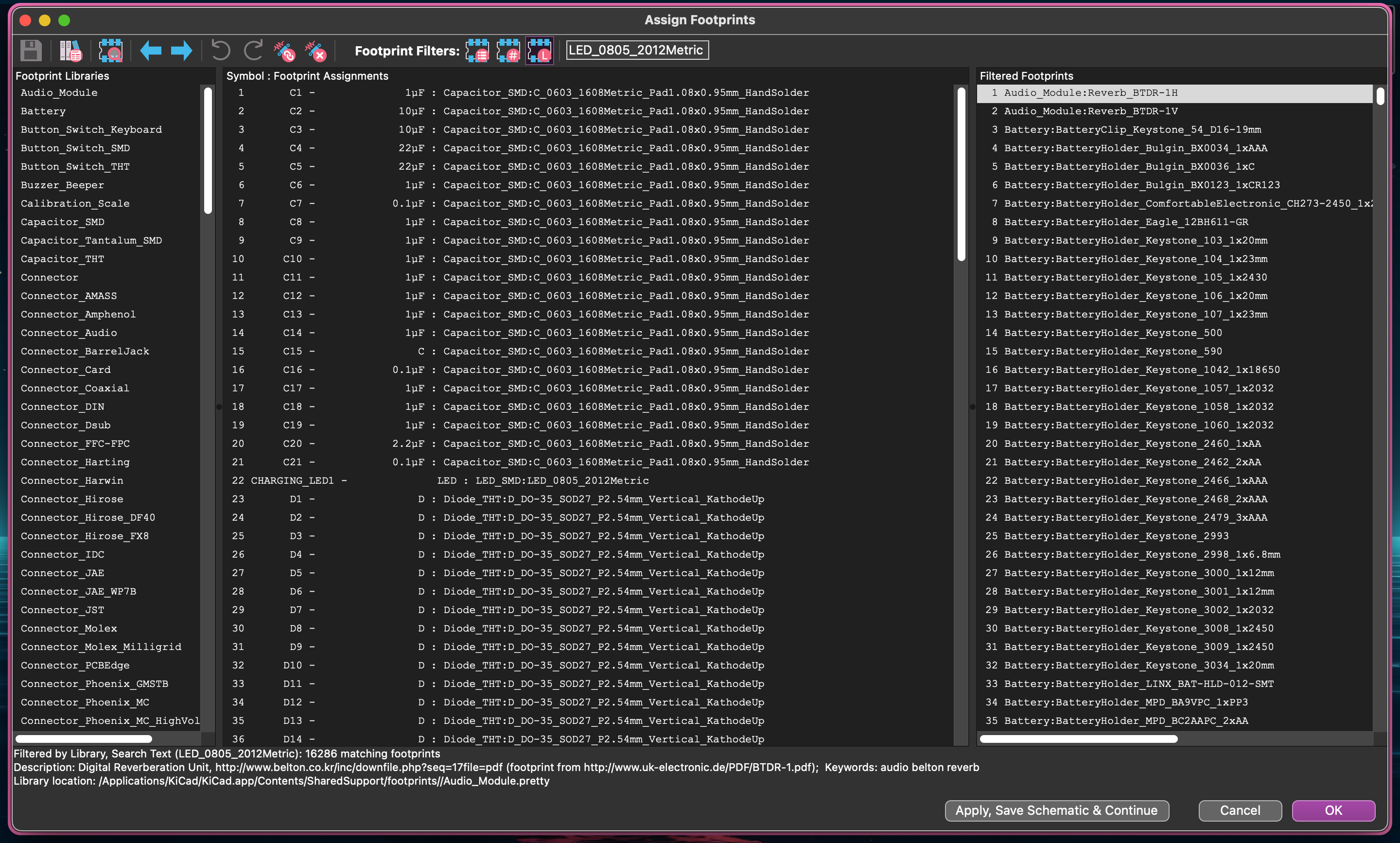
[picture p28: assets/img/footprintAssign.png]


## 2026-10-07 - Session 6 : PCB placement start !

I started arranging the stuff on the PCB, but today i had a lot to do other than techie stuff,
and went out with friends, then got my wallet stolen D: . Anyway after all that stress i wasn't really feeling like
working on the project, but i didn't wanna lose my streak so i did a little bit

i powered through arranging the key matrix properly, with all the diodes correctly aligned with the correct keys, and this was probably the most satisfying
part of the project - i think it looks **neat**

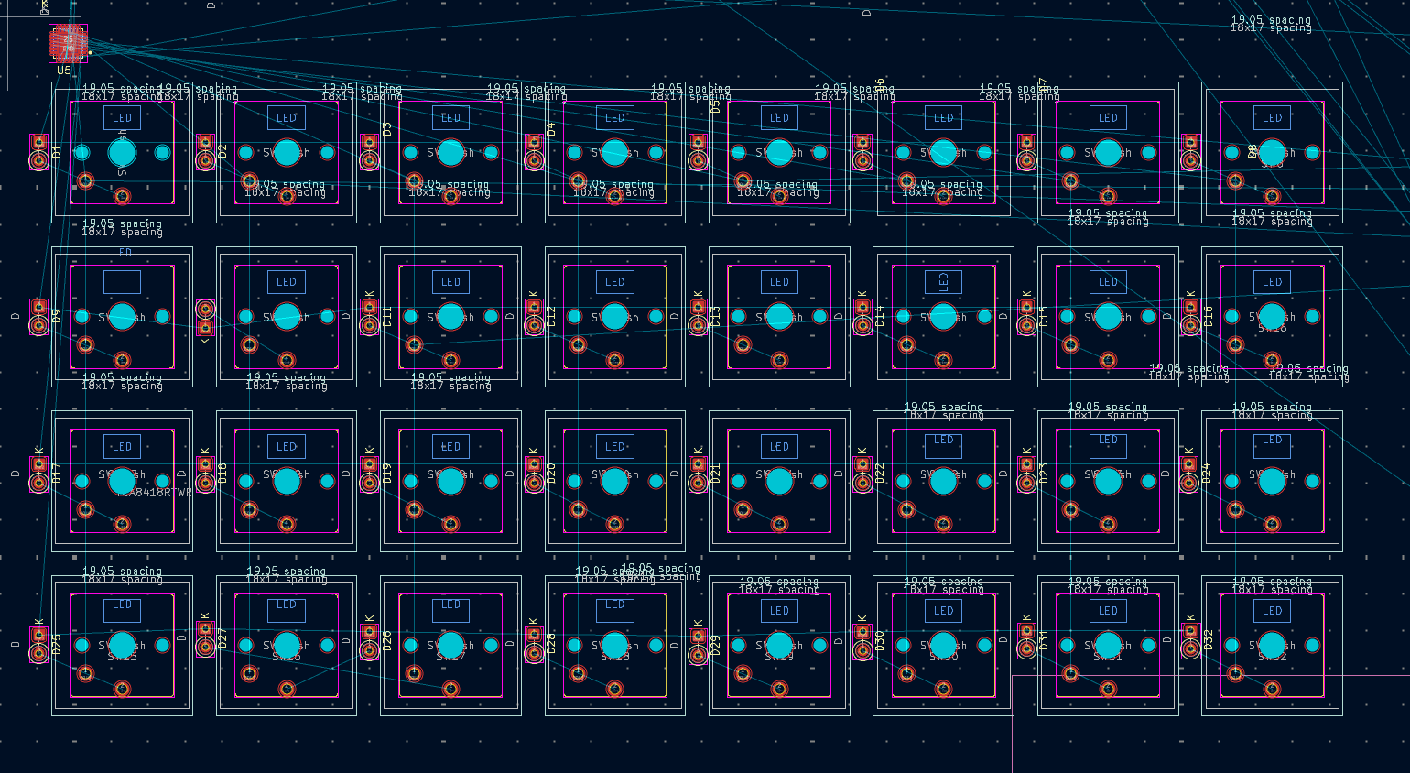
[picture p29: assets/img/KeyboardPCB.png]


then i started arranging like the Headers and stuff

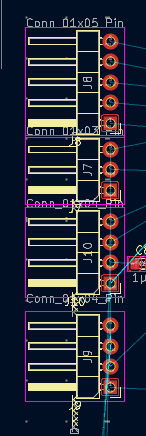
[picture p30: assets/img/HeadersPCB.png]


after that came the Audio section - and look at how tiny those chips are - im getting anxiety let alone looking at them, and am trying not to think about tryna
wire and then **solder** those tiny ass pins - look at that chip in comparison to a capacitor:

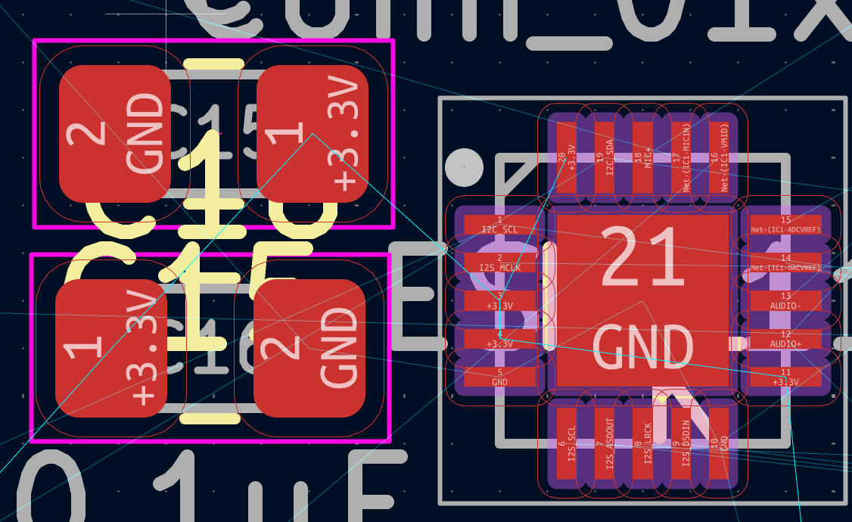
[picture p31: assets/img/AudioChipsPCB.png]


also i did the display part and used a 3D model i found of the component for measurements - i think its accurate enough

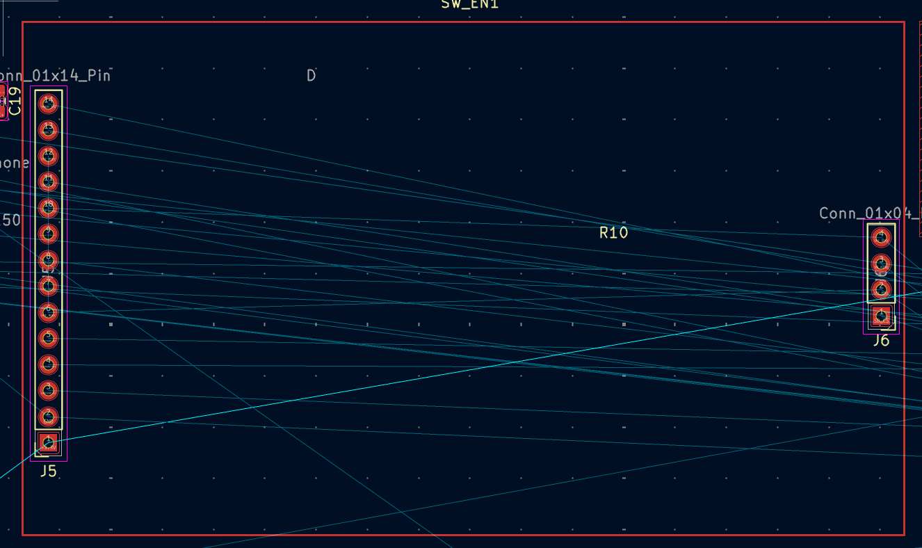
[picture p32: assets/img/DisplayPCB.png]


i also arranged a lil bit on the ESP and the like boot/power/key switches :

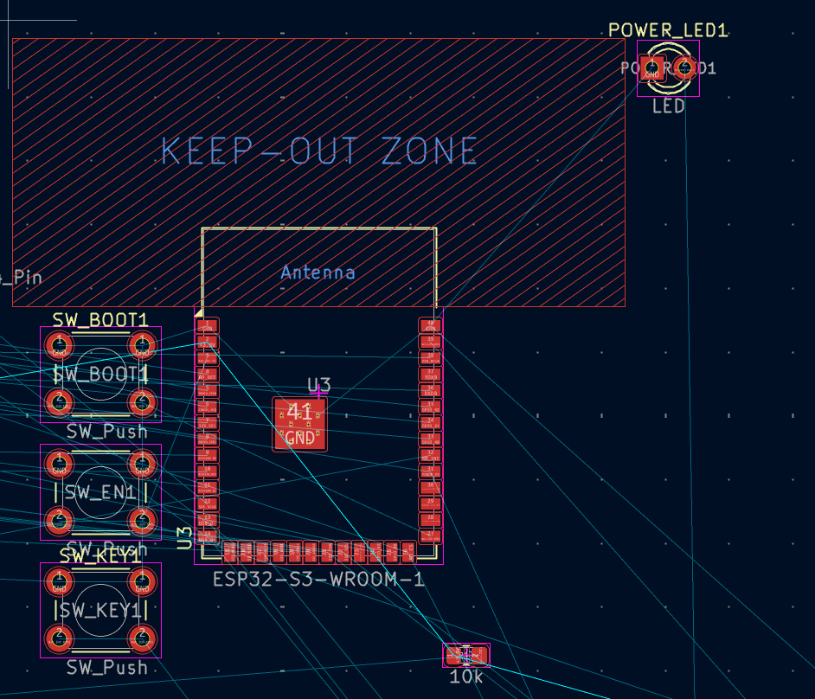
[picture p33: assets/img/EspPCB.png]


the rest i will do tomorrow - im really putting off placing the capacitors and resistors cause thats a pain in the ass -
id have to double check where every one goes cause the airwires go crazy cause of the Net labels i used and cause most of them are
decoupling capacitors, i have to check the schematic on how/where to place them, and im not looking forward to it.

Anyway thats all for today, see ya tmrw !

## 2026-10-07 - 2026-13-07: (~ 3 hours)

So i havent had time this weekend to really sit down and have a long KiCad session, so i did a few small sessions over the weekend :

I routed basically all the Power nets (+5V and +3.3V) and also the VBUS line from the USB-C receptacle to the IP5306. Next up i think i
will route the data lines from the USB-C receptacle, since those are high speed - there the choice is, do i route them as a differential pair or no ?

I looked online , and it seems i can _technically_ just route normal wires and it would be simpler ... that would be **boring**,
i wouldn't learn anything, and its not recommended - so im going the hard route, and routing a differential pair !

This will be ... **interesting** to say the least.

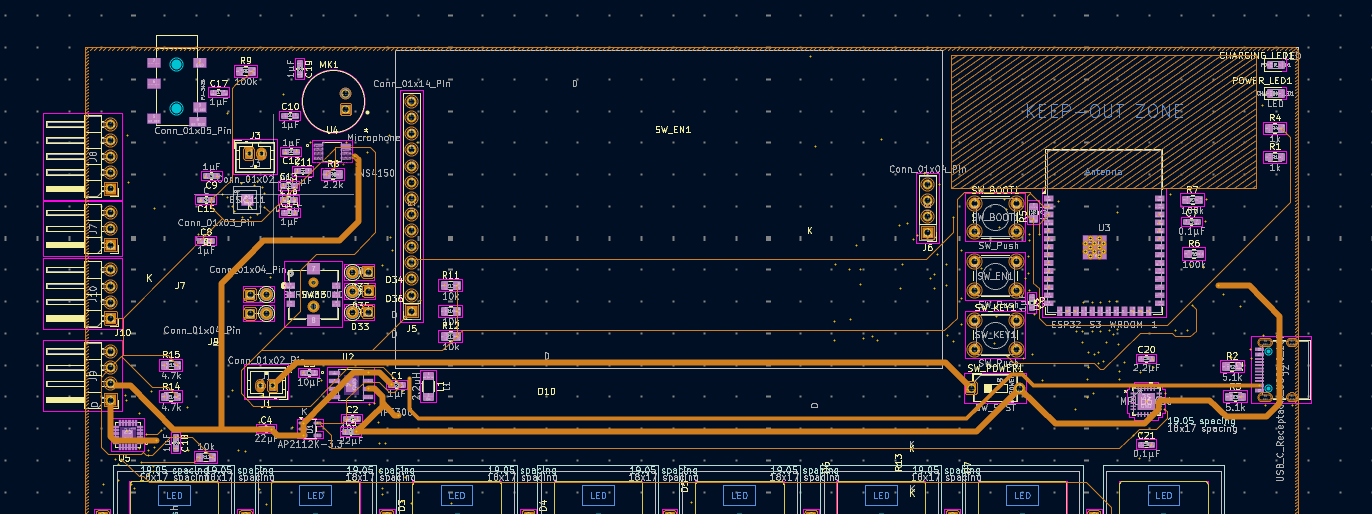
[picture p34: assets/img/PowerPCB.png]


## 2026-15-07: Wiring done ! (~ 6 hours)

Soo ... IM DONE BABYYYYYY

whooo
that was **something**
Anyway, i finished routing everything on the board, starting with most important to least important, and im finally done !
I used an _ungodly_ amount of vias, and cheated a bit sometimes by using the GND and PWR plan for some wires where there was just NO space.
I ran **DRC** and it started bitching about pin spacing on some of the fooprints and something bout the solder mask min width, but i was able to adjust some things in the board settings.
after that i still had 8 errors, but none of those were problematic actual errors, just KiCad complaining, so i was able to exclude those,
and now both me **and** KiCad are happy as a clam

anyway, brace yourself for the absolutely horrifying sight of my PCB :

also, while your already in shock, why not throw another one in - this PCB is **DAMN** expensive - apparently because this is a 4 layer BIG ASS (191 x 158 mm) PCB, it will cost a huge amount of money -
i wanted a quick price quote so i nicely zipped up my gerbers and uploaded em onto PCBway and its a whopping **140 dollars** in total - so yeah im givin up hope on this ever being S tier, so now fingers crossed that i get X tier approved, cause otherwise i am **_cooked_**

YEAHHHHH, so next part is either **case** or **firmware**

Programming this thing is gonna be like programming an OS for the first Iron Man suit (_tony stark built this with a box of scraps in a cave !_),
cause i have absolutely no idea how half those devices work, or even how to code hardware at all, so ill probably leave this part to my trusty partner
opencode, we'll see how it goes

Ok, so next up is the case

I have thought about this quite a bit, and this is my thought process :

i have 3d printed things before, and i really don't like the texture of the things, or just the _feel_ -
if this device is something ima use often, i want it to feel **_good_** in my hands, and normal 3d print filament doesn't do that.
So i looked at my options - one option is to use CNC and make a case out of ... **what ?** ... **METAL ?** or other material, and i would do the same 3d modeling asd always, and have done before,
like for my macropad and split keyboard. This is pretty simple, just make a bottom and a top with holes for everything, then add screw holes to connect them while PCB is inside and tadaa, you have a case.
Problem is, thats _boring_. Instead i had one more idea - **woodworking**. My local makespace has a (german incoming) **Hobelhoehle** - basically a wood workshop on steroids, and i've never gotten a chance to use it.
So im thinking of making a wood case from scratch with a nice finish - you might be thinking it will feel rough, but you'd be surprised how smooth and premium feeling **wood** can get.

So i'll think about it a bit, but this is the option im leaning towards, because its :

- a good use of the wood workshop
- a learning experience
- i would say better feeling
- more accurate - cause i can assemble the PCB myself, then measure everything and make sure it fits, instead of potentially spending hours on a 3d print that might not fit cause of bad blueprints or measurements on the component
- _FUNNNNN_
- **FUNN**

so yeah, ill think about it.

Also, i feel like im in an Andy Weir book with all the logging and journaling. i feel like the dude from the martian, Mark Watney. Exceot i wont die if i mess shit up. Eh.

Heres the final PCB :

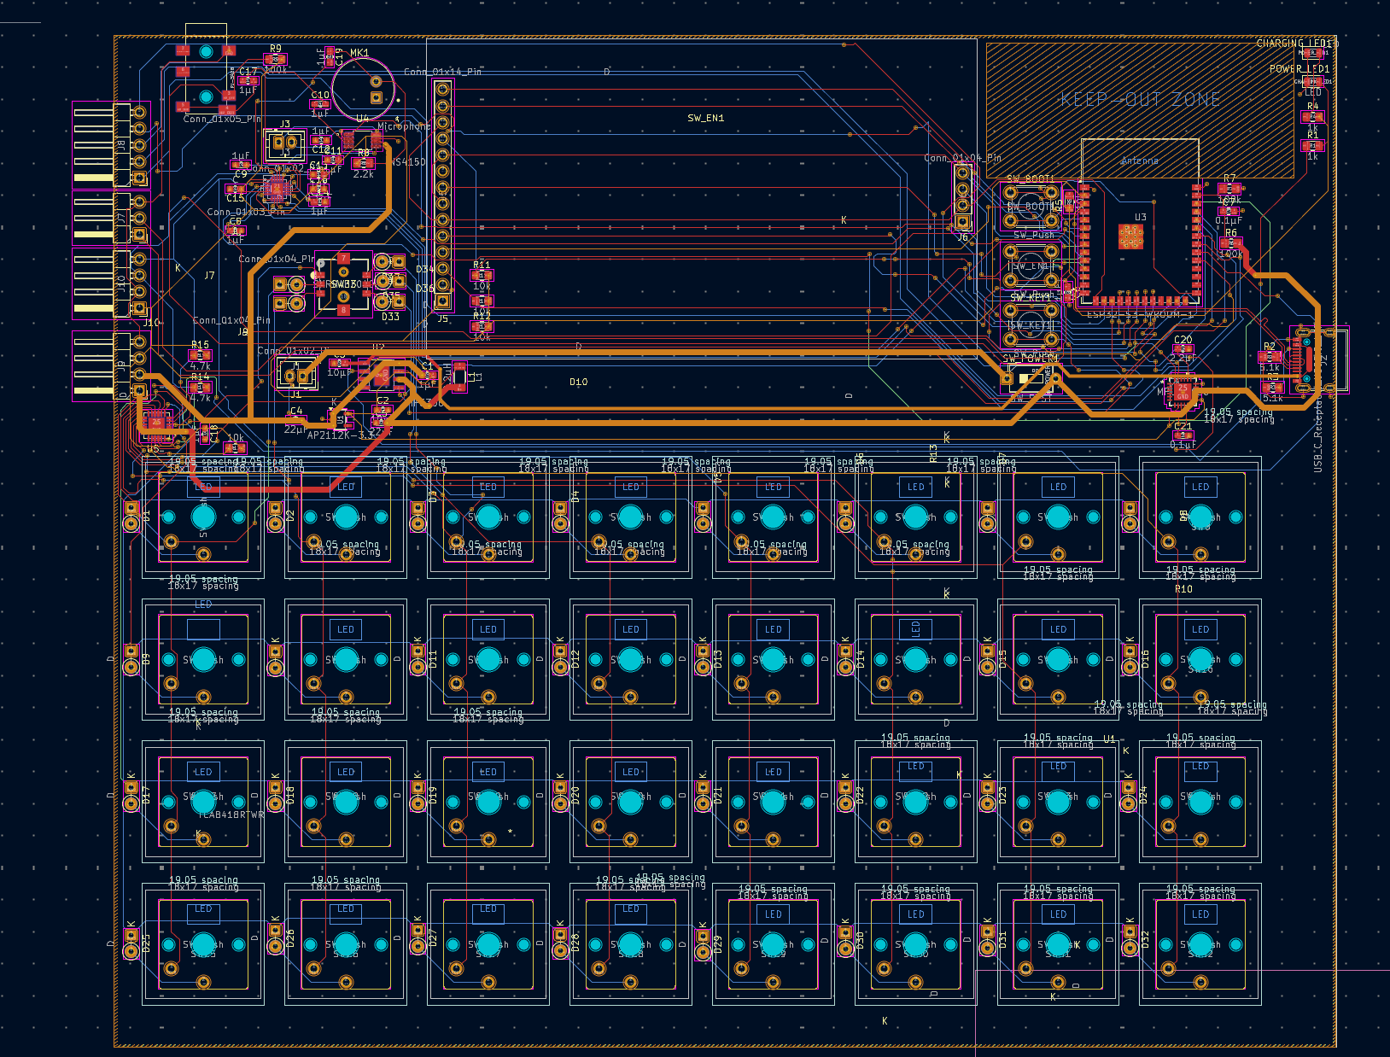
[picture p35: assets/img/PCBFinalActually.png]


Ive also filled the Power sheet with ground cuz apparently thats better

## July 26 : Case T-T

I was overruled by the feedback gods, and was told by nice dudes who give feedback (shout out to @zsharpminor, my first friend ever on Hack Club) that even if im making a wood case i need a CAD model - cause X tiers just need that amount of polish.
Ugh.

So i got to work, and im sorry that im only journaling now, i kinda forgot about it.

First thing i did was make the PCB 3d model by getting the step files of all the _important_ Components and adding them to the PCB in KiCad - i then exported the 3d model and imported in to my onshape, which is where i work for 3d modeling (it works in the browser).

I made a few measurements with the measure tool on the PCB and just made an outline of the case and where there need to be holes for the components.
I decided to make the bottom shell's floor 2 mm thick, and the walls 8mm tall - then the top is 2mm tall, making the entire thing 12mm (1.2cm) high, which is reasonable and still allows access to the extreme low profile switches.
The walls are half a cm thick (5mm)

I made the Case Bottom which is just a shell for the PCB :



And the Case Top (including cool panda logo) :



After that i made a demonstration of how the thing will come together by adding screw holes and putting the two halves & the PCB 3d model from KiCad together :



Im pretty much done now, what im going to do now is just add these same pics and the info to my README, and push to Github - then im done !

:D

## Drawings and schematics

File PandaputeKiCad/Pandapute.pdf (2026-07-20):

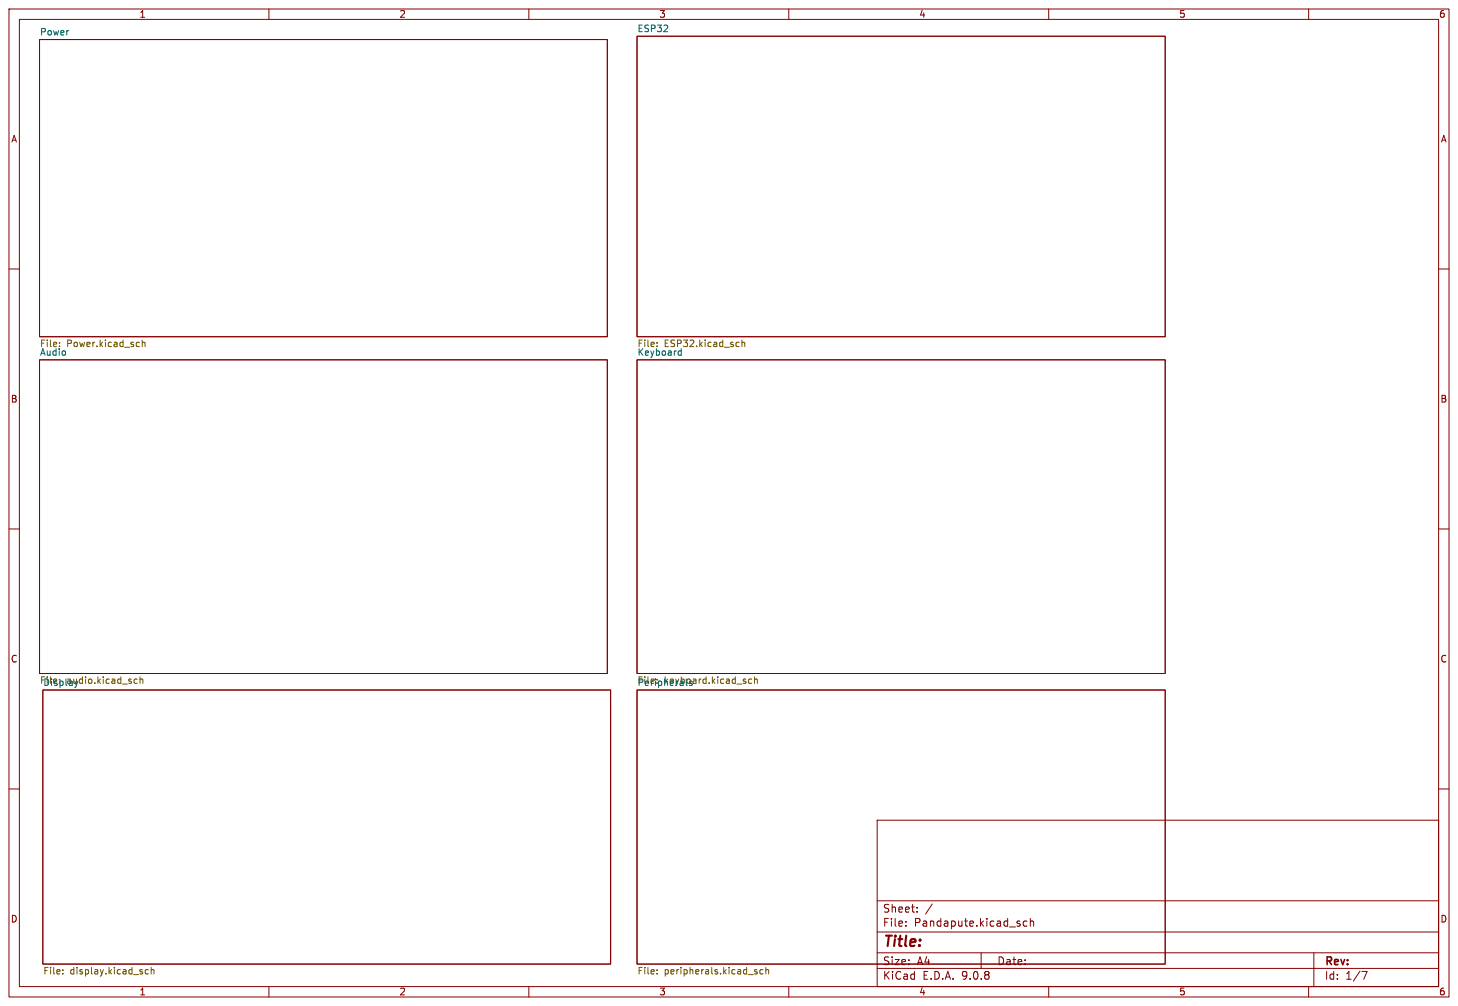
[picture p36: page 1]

Audio File: Displayaudio.kicad_sch File: display.kicad_sch

Id: 1/7 Title: File: Pandapute.kicad_sch Sheet: /
E.D.A. 9.0.8 Size: A4 | Rev: | D Date: KiCad

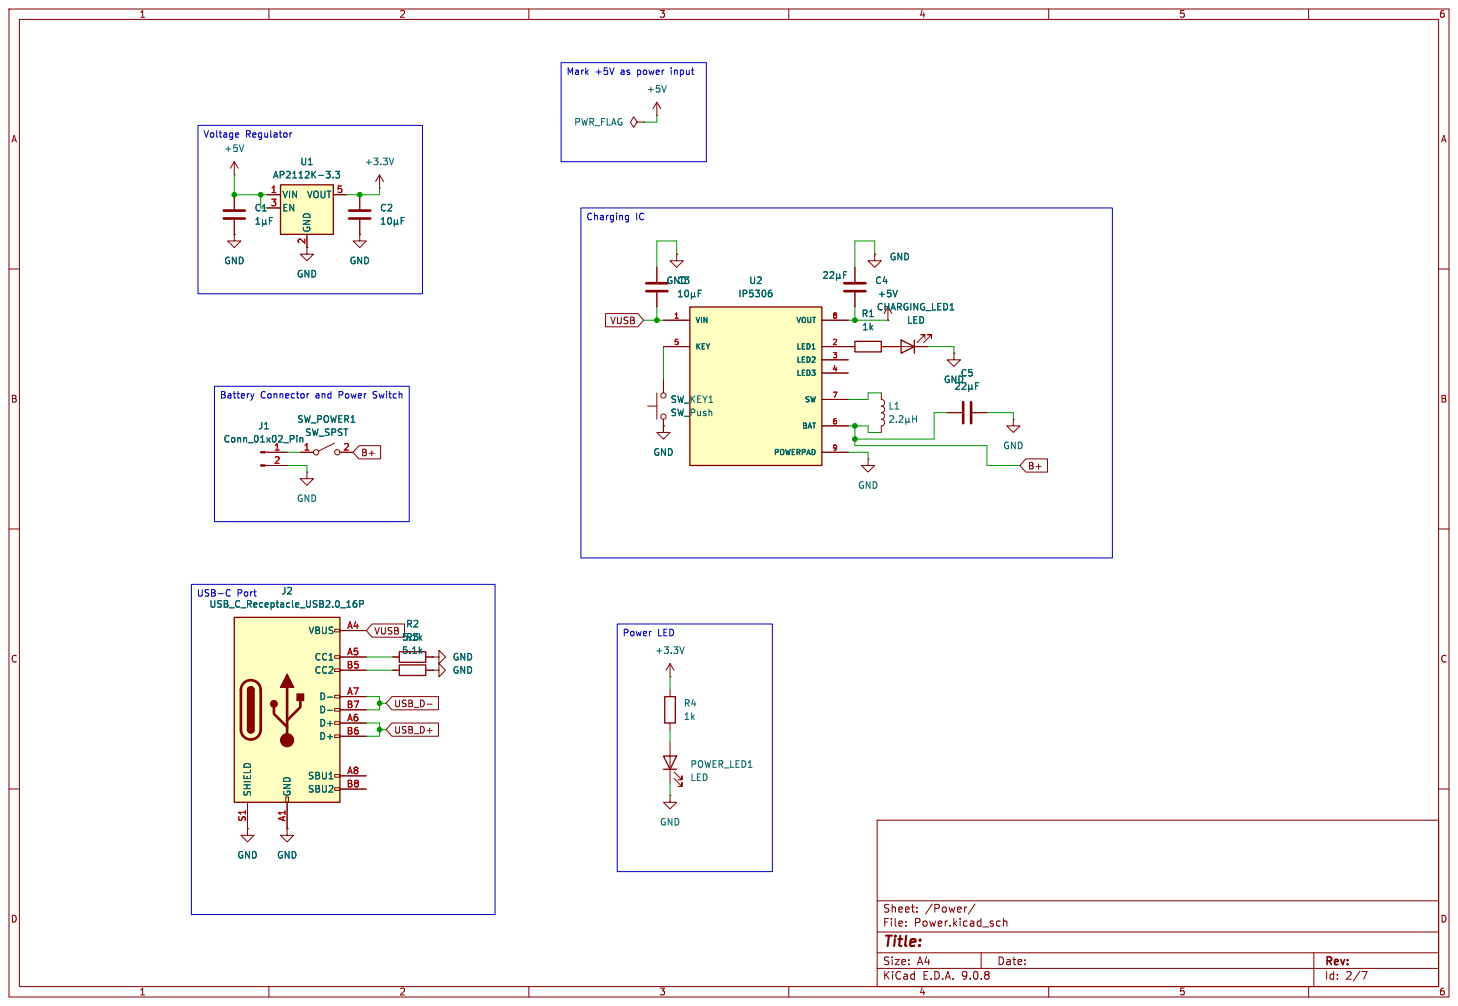
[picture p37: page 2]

Id: 2/7 Title: File: Power.kicad_sch Sheet: /Power/

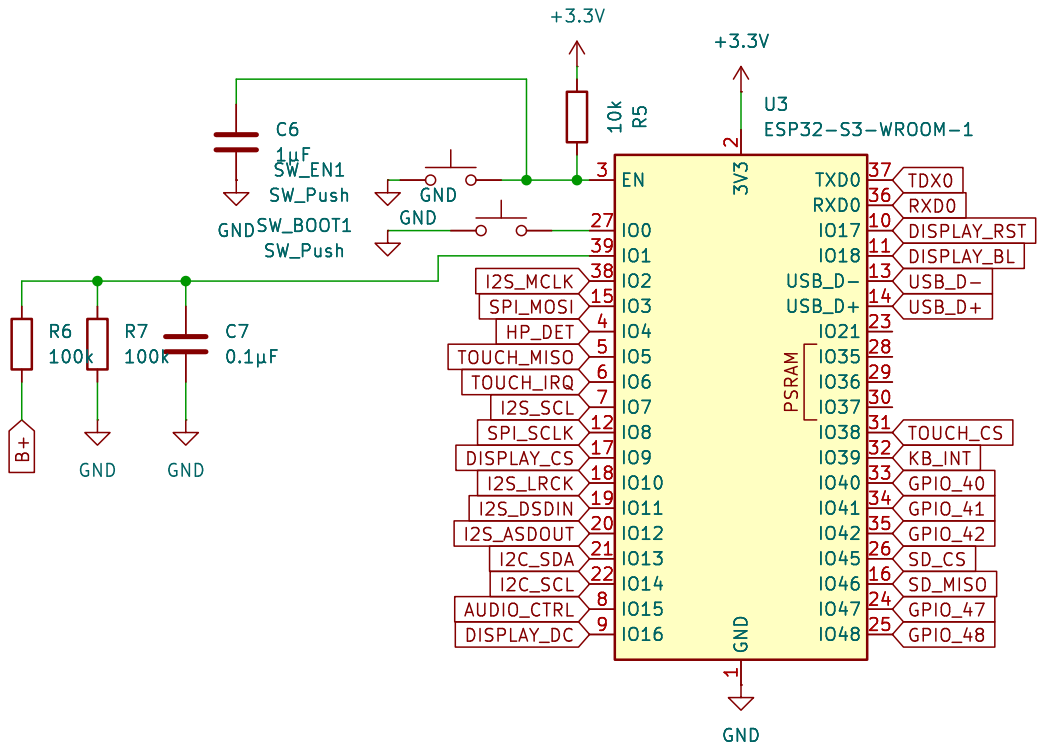
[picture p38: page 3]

Id: 3/7 Title: File: ESP32.kicad_sch Sheet: /ESP32/

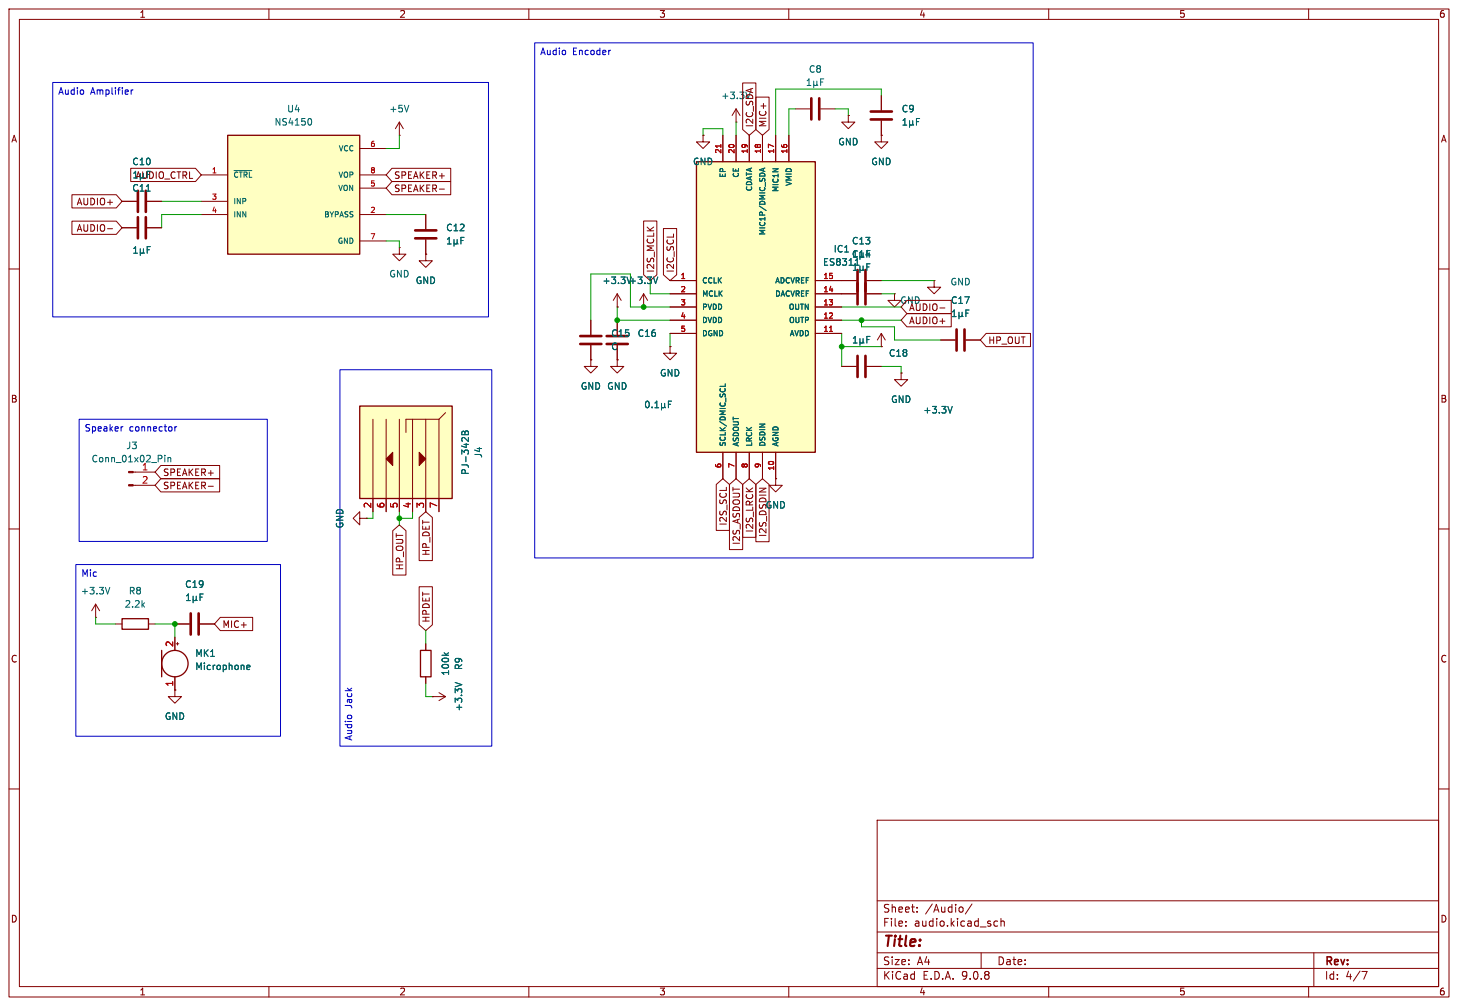
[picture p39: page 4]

Id: 4/7 Title: File: audio.kicad_sch Sheet: /Audio/

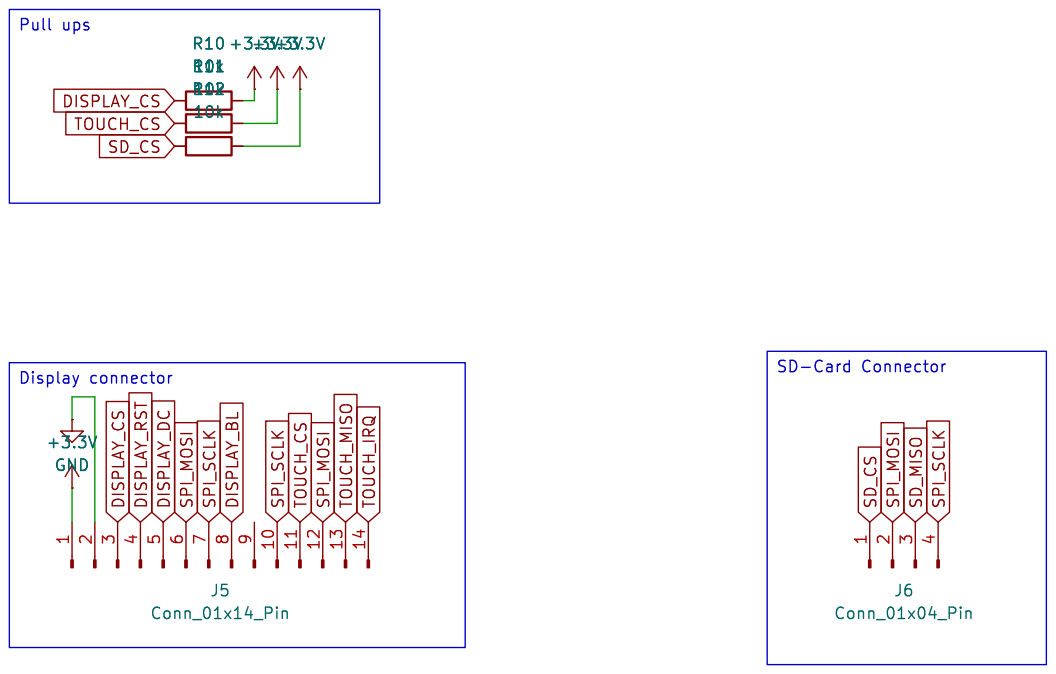
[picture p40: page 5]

Id: 5/7 Title: File: display.kicad_sch Sheet: /Display/

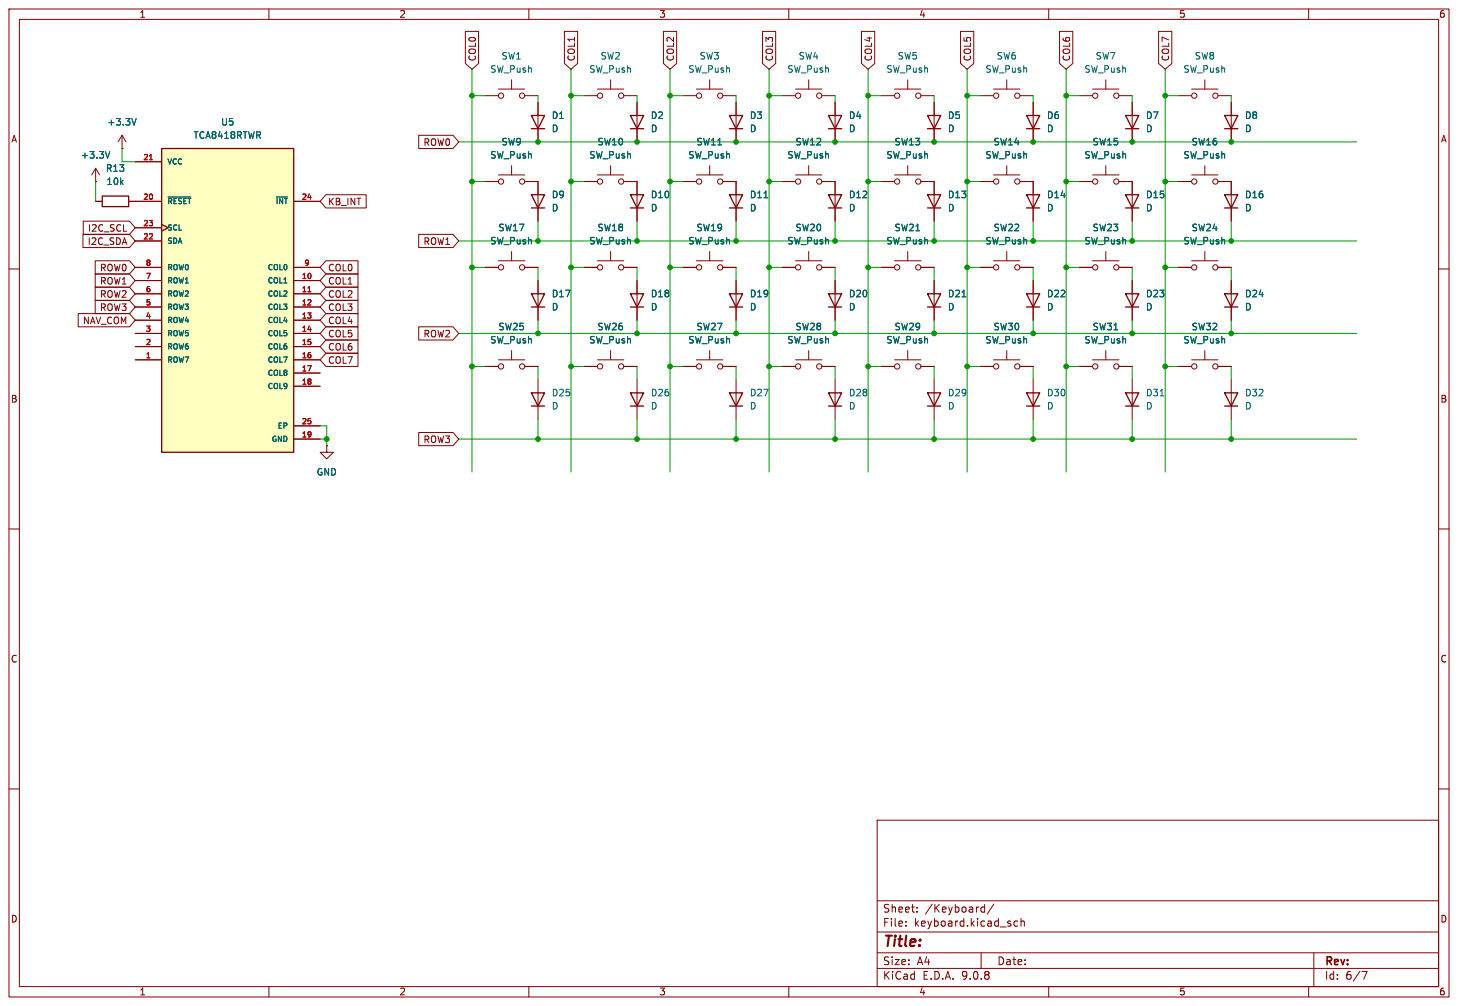
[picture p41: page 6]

Id: 6/7 Title: File: keyboard.kicad_sch Sheet: /Keyboard/

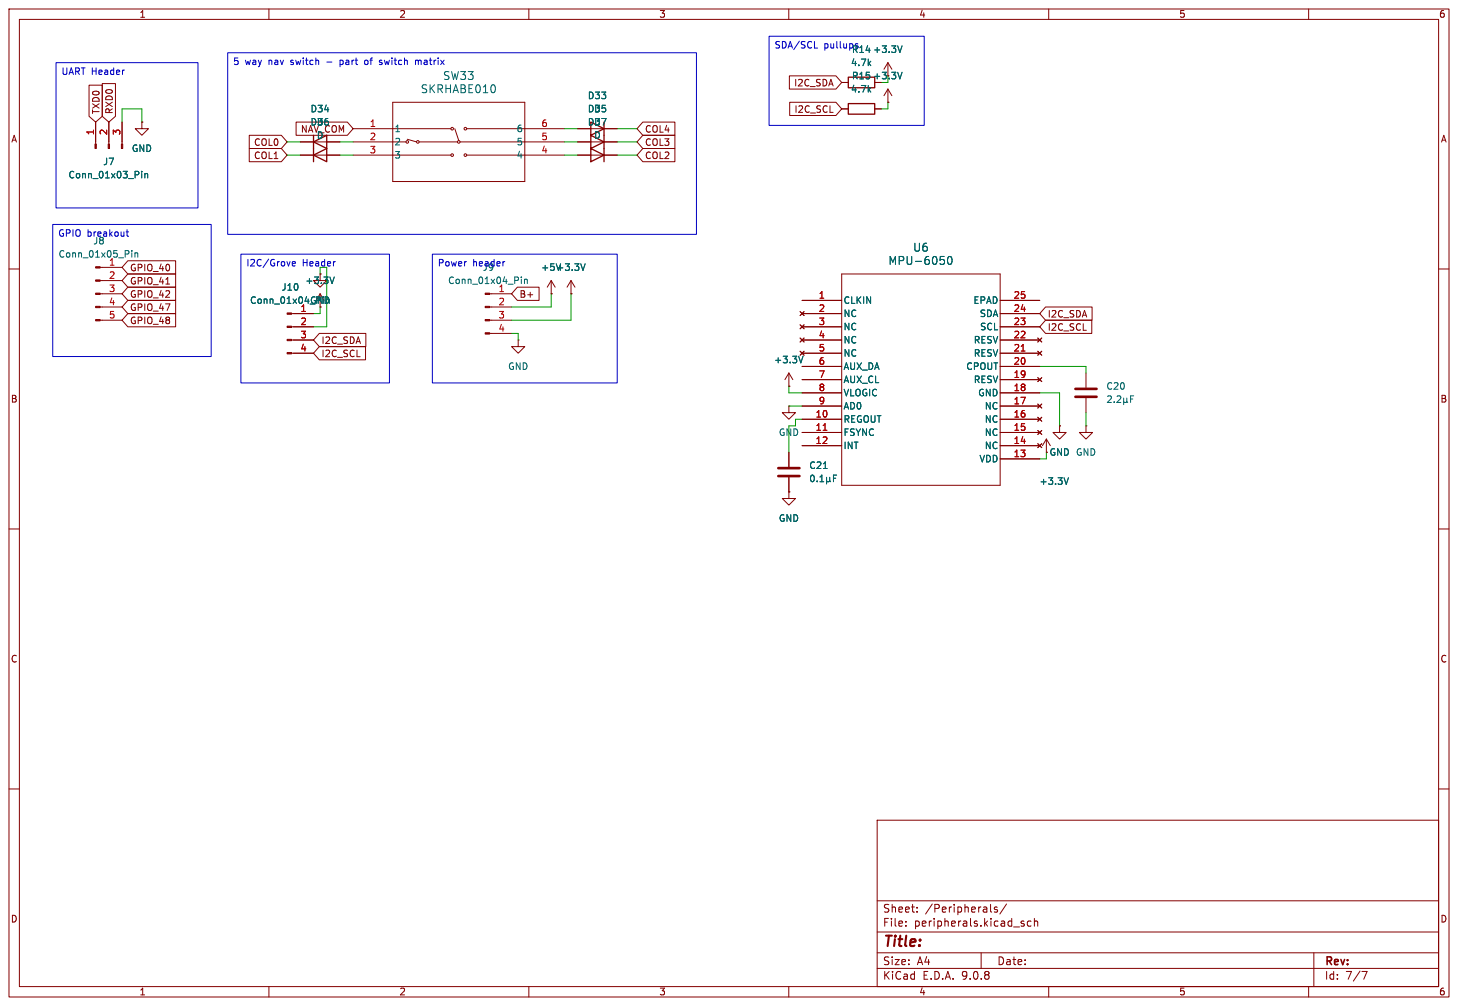
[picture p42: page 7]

Id: 7/7 Title: File: peripherals.kicad_sch Sheet: /Peripherals/

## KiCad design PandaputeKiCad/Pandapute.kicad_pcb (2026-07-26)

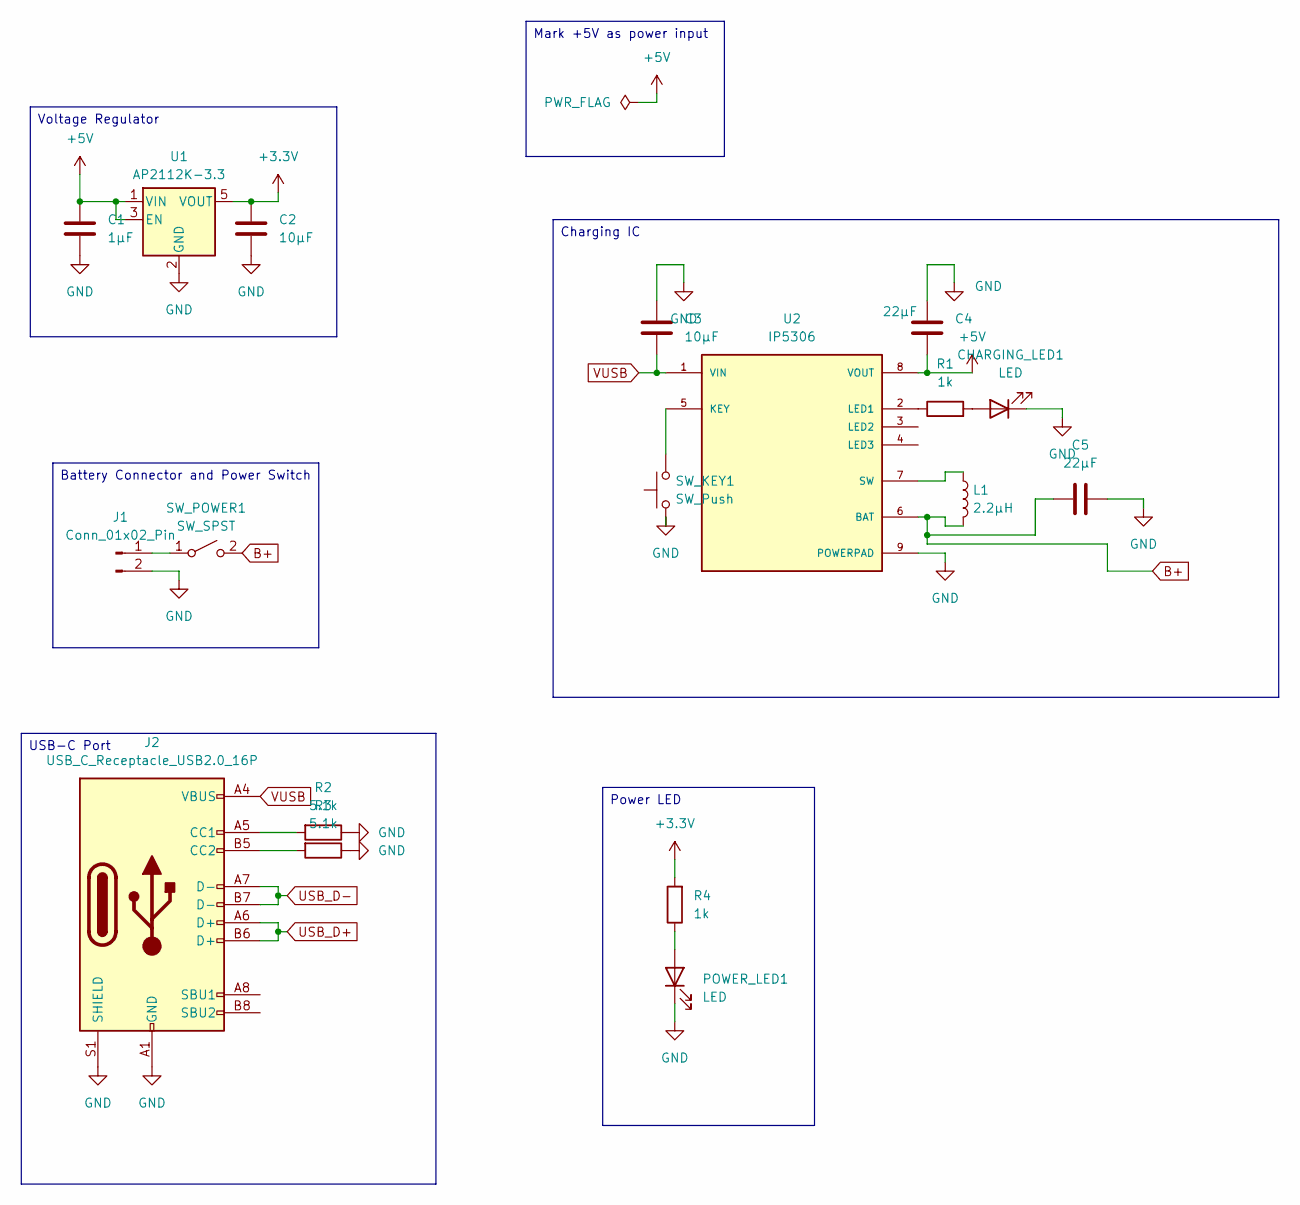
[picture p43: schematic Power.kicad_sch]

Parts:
C1: 1µF; C_0603_1608Metric_Pad1.08x0.95mm_HandSolder
C2, C3: 10µF; C_0603_1608Metric_Pad1.08x0.95mm_HandSolder
C4, C5: 22µF; C_0603_1608Metric_Pad1.08x0.95mm_HandSolder
CHARGING_LED1: LED; LED_0805_2012Metric
J1: Conn_01x02_Pin; JST_PH_B2B-PH-K_1x02_P2.00mm_Vertical
J2: USB_C_Receptacle_USB2.0_16P; USB_C_Receptacle_HRO_TYPE-C-31-M-12
L1: 2.2µH; L_1206_3216Metric_Pad1.22x1.90mm_HandSolder
POWER_LED1: LED; LED_0805_2012Metric
R1, R4: 1k; R_0805_2012Metric_Pad1.20x1.40mm_HandSolder
R2, R3: 5.1k; R_0805_2012Metric_Pad1.20x1.40mm_HandSolder
SW_KEY1: SW_Push; SW_PUSH_6mm_H5mm
SW_POWER1: SW_SPST; SW_DIP_SPSTx01_Slide_6.7x4.1mm_W7.62mm_P2.54mm_LowProfile
U1: AP2112K-3.3; SOT-23-5
U2: IP5306; PARTREV 1.31

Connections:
+3.3V: C2.1, R4.2, U1.5 (VOUT); also elsewhere on the board
+5V: C1.1, C4.2, U1.1 (VIN), U1.3 (EN), U2.8 (VOUT); also elsewhere on the board
B+: C5.2, L1.2, SW_POWER1.2 (B), U2.6 (BAT); also elsewhere on the board
GND: C1.2, C2.2, C3.1, C4.1, C5.1, CHARGING_LED1.1 (K), J1.2, J2.A1 (GND), J2.A12 (GND), J2.B1 (GND), J2.B12 (GND), J2.S1 (SHIELD), POWER_LED1.1 (K), R2.1, R3.1, SW_KEY1.1, U1.2 (GND), U2.9 (POWERPAD); also elsewhere on the board
unnamed: CHARGING_LED1.2 (A), R1.2
unnamed: J1.1, SW_POWER1.1 (A)
unnamed: J2.A5 (CC1), R2.2
unnamed: J2.B5 (CC2), R3.2
unnamed: POWER_LED1.2 (A), R4.1
unnamed: SW_KEY1.2, U2.5 (KEY)
unnamed: R1.1, U2.2 (LED1)
unnamed: L1.1, U2.7 (SW)
USB_D+: J2.A6 (D+), J2.B6 (D+); also elsewhere on the board
USB_D-: J2.A7 (D-), J2.B7 (D-); also elsewhere on the board
VUSB: C3.2, J2.A4 (VBUS), J2.A9 (VBUS), J2.B4 (VBUS), J2.B9 (VBUS), U2.1 (VIN)

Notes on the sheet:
Charging IC
Mark +5V as power input
Power LED
USB-C Port
Voltage Regulator
Battery Connector and Power Switch

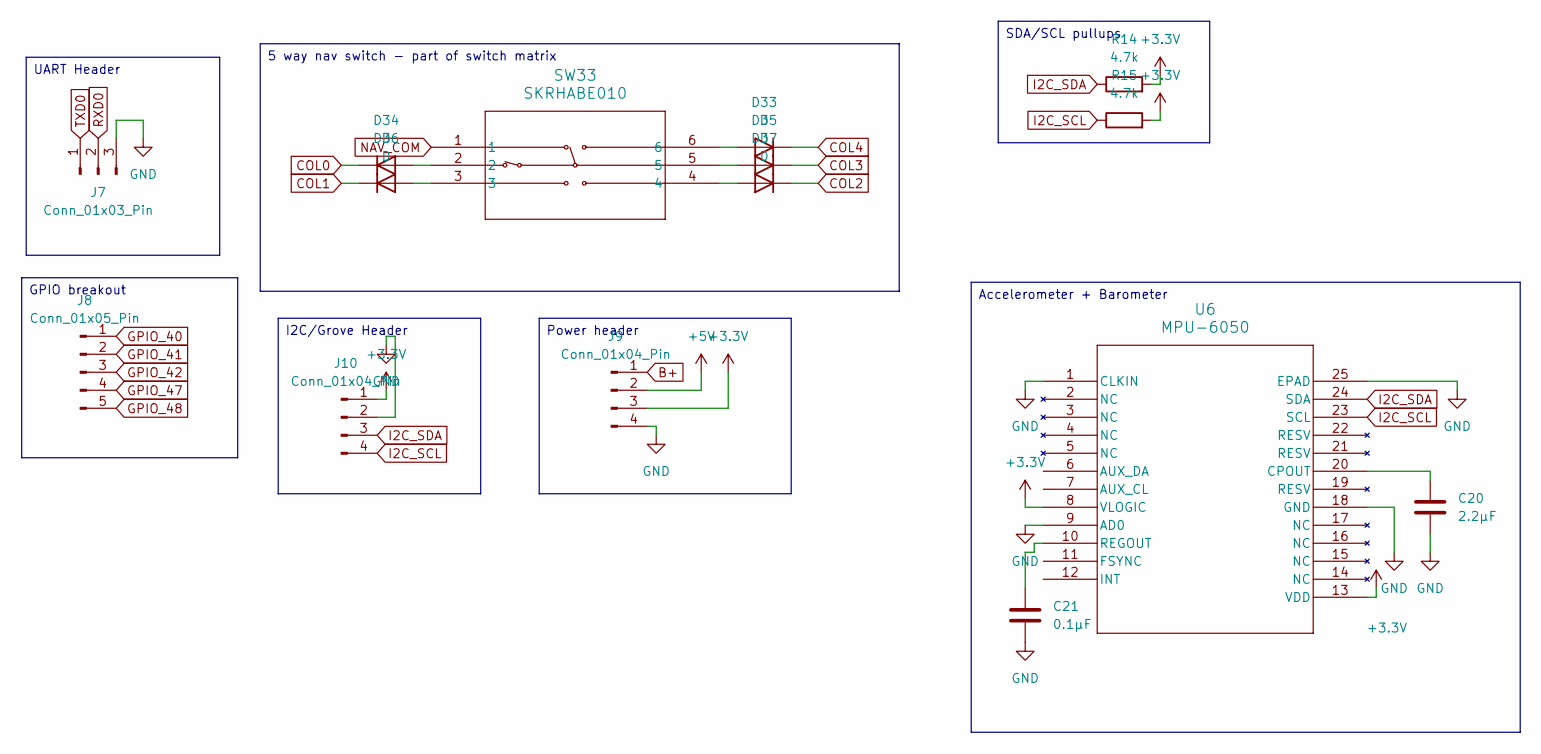
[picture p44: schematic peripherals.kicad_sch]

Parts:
C20: 2.2µF; C_0603_1608Metric_Pad1.08x0.95mm_HandSolder
C21: 0.1µF; C_0603_1608Metric_Pad1.08x0.95mm_HandSolder
D33, D34, D35, D36, D37: D; D_DO-35_SOD27_P2.54mm_Vertical_KathodeUp
J7: Conn_01x03_Pin; PinHeader_1x03_P2.54mm_Horizontal
J8: Conn_01x05_Pin; PinHeader_1x05_P2.54mm_Horizontal
J9, J10: Conn_01x04_Pin; PinHeader_1x04_P2.54mm_Horizontal
R14, R15: 4.7k; R_0805_2012Metric_Pad1.20x1.40mm_HandSolder
SW33: SKRHABE010; SKRHABE010_ALPS
U6: MPU-6050; MPU6050

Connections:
+3.3V: J9.3, J10.1, R14.2, R15.2, U6.8 (VLOGIC), U6.13 (VDD); also elsewhere on the board
+5V: J9.2; also elsewhere on the board
B+: J9.1; also elsewhere on the board
COL0: D34.1 (K); also elsewhere on the board
COL1: D36.1 (K); also elsewhere on the board
COL2: D37.1 (K); also elsewhere on the board
COL3: D35.1 (K); also elsewhere on the board
COL4: D33.1 (K); also elsewhere on the board
GND: C20.2, C21.2, J7.3, J9.4, J10.2, U6.1 (CLKIN), U6.9 (AD0), U6.18 (GND), U6.25 (EPAD); also elsewhere on the board
GPIO_40: J8.1; also elsewhere on the board
GPIO_41: J8.2; also elsewhere on the board
GPIO_42: J8.3; also elsewhere on the board
GPIO_47: J8.4; also elsewhere on the board
GPIO_48: J8.5; also elsewhere on the board
I2C_SCL: J10.4, R15.1, U6.23 (SCL); also elsewhere on the board
I2C_SDA: J10.3, R14.1, U6.24 (SDA); also elsewhere on the board
NAV_COM: SW33.1; also elsewhere on the board
unnamed: D33.2 (A), SW33.6
unnamed: D34.2 (A), SW33.2
unnamed: D35.2 (A), SW33.5
unnamed: D36.2 (A), SW33.3
unnamed: D37.2 (A), SW33.4
unnamed: C20.1, U6.20 (CPOUT)
unnamed: C21.1, U6.10 (REGOUT)
RXD0: J7.2; also elsewhere on the board
TXD0: J7.1; also elsewhere on the board

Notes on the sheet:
UART Header
Accelerometer + Barometer
GPIO breakout
5 way nav switch - part of switch matrix
SDA/SCL pullups
Power header
I2C/Grove Header

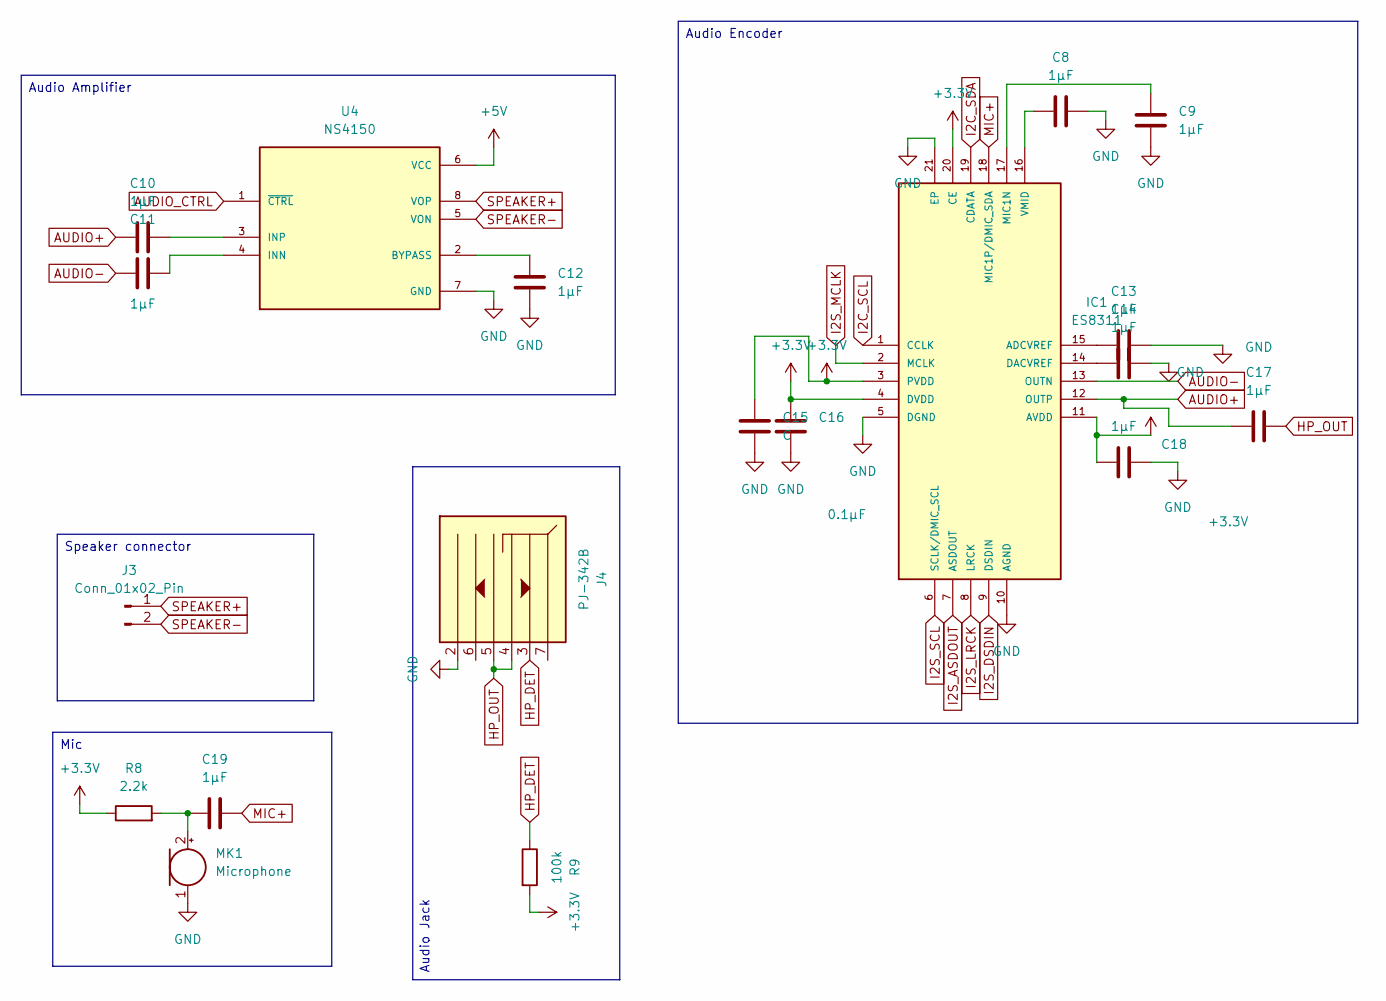
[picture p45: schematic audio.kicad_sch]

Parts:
C8, C9, C10, C11, C12, C13, C14, C17, C18, C19: 1µF; C_0603_1608Metric_Pad1.08x0.95mm_HandSolder
C15: C; C_0603_1608Metric_Pad1.08x0.95mm_HandSolder
C16: 0.1µF; C_0603_1608Metric_Pad1.08x0.95mm_HandSolder
IC1: ES8311; MANUFACTURER_PART_NUMBER ES8311
J3: Conn_01x02_Pin; JST_PH_B2B-PH-K_1x02_P2.00mm_Vertical
J4: PJ-342B
MK1: Microphone; MIC_CMA-4544PF-W
R8: 2.2k; R_0805_2012Metric_Pad1.20x1.40mm_HandSolder
R9: 100k; R_0805_2012Metric_Pad1.20x1.40mm_HandSolder
U4: NS4150; PARTREV 1.1

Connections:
+3.3V: C15.1, C16.1, C18.1, IC1.3 (PVDD), IC1.4 (DVDD), IC1.11 (AVDD), IC1.20 (CE), R8.1, R9.2; also elsewhere on the board
+5V: U4.6 (VCC); also elsewhere on the board
AUDIO+: C10.2, C17.1, IC1.12 (OUTP)
AUDIO-: C11.1, IC1.13 (OUTN)
AUDIO_CTRL: U4.1 (~CTRL); also elsewhere on the board
GND: C8.2, C9.2, C12.2, C13.2, C14.2, C15.2, C16.2, C18.2, IC1.5 (DGND), IC1.10 (AGND), IC1.21 (EP), J4.2, MK1.1 (-), U4.7 (GND); also elsewhere on the board
HP_DET: J4.3, R9.1; also elsewhere on the board
HP_OUT: C17.2, J4.4, J4.5
I2C_SCL: IC1.1 (CCLK); also elsewhere on the board
I2C_SDA: IC1.19 (CDATA); also elsewhere on the board
I2S_ASDOUT: IC1.7 (ASDOUT); also elsewhere on the board
I2S_DSDIN: IC1.9 (DSDIN); also elsewhere on the board
I2S_LRCK: IC1.8 (LRCK); also elsewhere on the board
I2S_MCLK: IC1.2 (MCLK); also elsewhere on the board
I2S_SCL: IC1.6 (SCLK/DMIC_SCL); also elsewhere on the board
MIC+: C19.2, IC1.18 (MIC1P/DMIC_SDA)
unnamed: C13.1, IC1.15 (ADCVREF)
unnamed: C14.1, IC1.14 (DACVREF)
unnamed: C9.1, IC1.17 (MIC1N)
unnamed: C8.1, IC1.16 (VMID)
unnamed: C19.1, MK1.2 (+), R8.2
unnamed: C12.1, U4.2 (BYPASS)
unnamed: C11.2, U4.4 (INN)
unnamed: C10.1, U4.3 (INP)
SPEAKER+: J3.1, U4.8 (VOP)
SPEAKER-: J3.2, U4.5 (VON)

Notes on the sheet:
Audio Jack
Audio Amplifier
Mic
Speaker connector
Audio Encoder

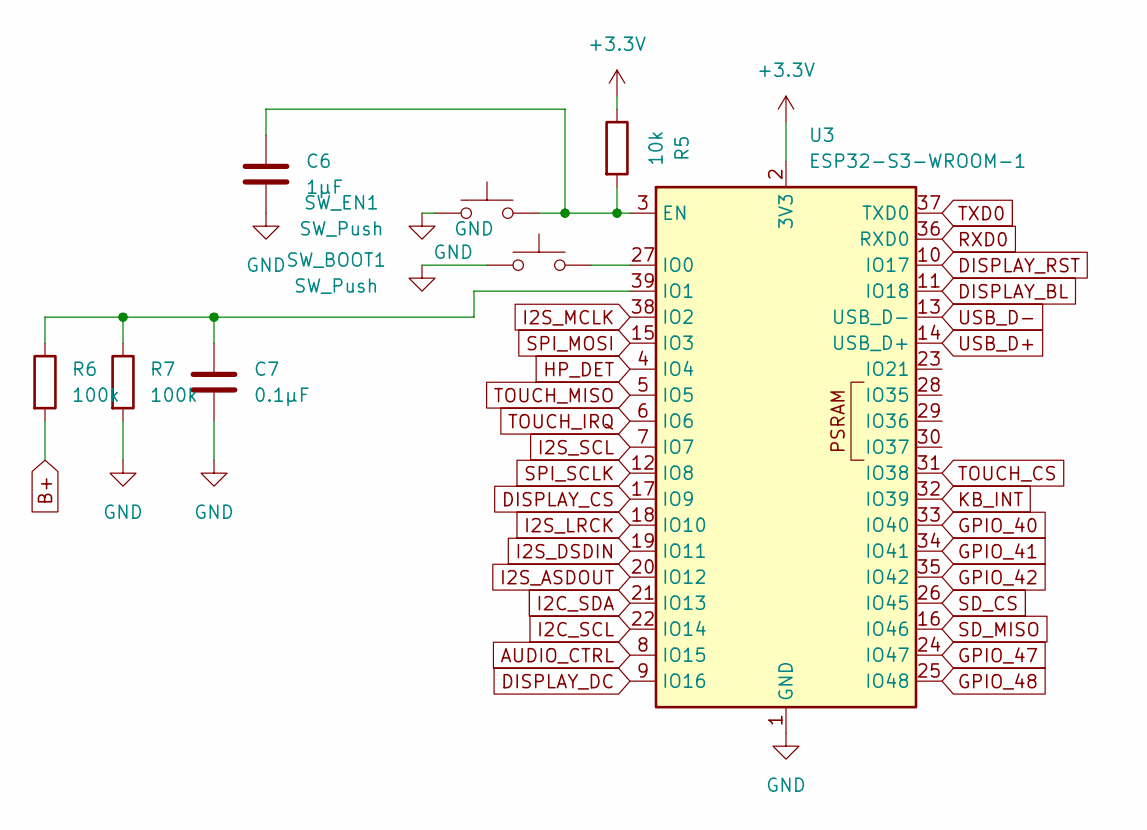
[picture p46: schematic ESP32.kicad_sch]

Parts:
C6: 1µF; C_0603_1608Metric_Pad1.08x0.95mm_HandSolder
C7: 0.1µF; C_0603_1608Metric_Pad1.08x0.95mm_HandSolder
R5: 10k; R_0805_2012Metric_Pad1.20x1.40mm_HandSolder
R6, R7: 100k; R_0805_2012Metric_Pad1.20x1.40mm_HandSolder
SW_BOOT1: SW_Push; SW_PUSH_6mm_H5mm
SW_EN1: SW_Push; SW_PUSH_6mm_H5mm
U3: ESP32-S3-WROOM-1

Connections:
+3.3V: R5.1, U3.2 (3V3); also elsewhere on the board
AUDIO_CTRL: U3.8 (IO15); also elsewhere on the board
B+: R6.2; also elsewhere on the board
DISPLAY_BL: U3.11 (IO18); also elsewhere on the board
DISPLAY_CS: U3.17 (IO9); also elsewhere on the board
DISPLAY_DC: U3.9 (IO16); also elsewhere on the board
DISPLAY_RST: U3.10 (IO17); also elsewhere on the board
GND: C6.2, C7.2, R7.2, SW_BOOT1.1, SW_EN1.1, U3.1 (GND), U3.40 (GND), U3.41 (GND); also elsewhere on the board
GPIO_40: U3.33 (IO40); also elsewhere on the board
GPIO_41: U3.34 (IO41); also elsewhere on the board
GPIO_42: U3.35 (IO42); also elsewhere on the board
GPIO_47: U3.24 (IO47); also elsewhere on the board
GPIO_48: U3.25 (IO48); also elsewhere on the board
HP_DET: U3.4 (IO4); also elsewhere on the board
I2C_SCL: U3.22 (IO14); also elsewhere on the board
I2C_SDA: U3.21 (IO13); also elsewhere on the board
I2S_ASDOUT: U3.20 (IO12); also elsewhere on the board
I2S_DSDIN: U3.19 (IO11); also elsewhere on the board
I2S_LRCK: U3.18 (IO10); also elsewhere on the board
I2S_MCLK: U3.38 (IO2); also elsewhere on the board
I2S_SCL: U3.7 (IO7); also elsewhere on the board
KB_INT: U3.32 (IO39); also elsewhere on the board
unnamed: C6.1, R5.2, SW_EN1.2, U3.3 (EN)
unnamed: SW_BOOT1.2, U3.27 (IO0)
unnamed: C7.1, R6.1, R7.1, U3.39 (IO1)
RXD0: U3.36 (RXD0); also elsewhere on the board
SD_CS: U3.26 (IO45); also elsewhere on the board
SD_MISO: U3.16 (IO46); also elsewhere on the board
SPI_MOSI: U3.15 (IO3); also elsewhere on the board
SPI_SCLK: U3.12 (IO8); also elsewhere on the board
TOUCH_CS: U3.31 (IO38); also elsewhere on the board
TOUCH_IRQ: U3.6 (IO6); also elsewhere on the board
TOUCH_MISO: U3.5 (IO5); also elsewhere on the board
TXD0: U3.37 (TXD0); also elsewhere on the board
USB_D+: U3.14 (USB_D+); also elsewhere on the board
USB_D-: U3.13 (USB_D-); also elsewhere on the board

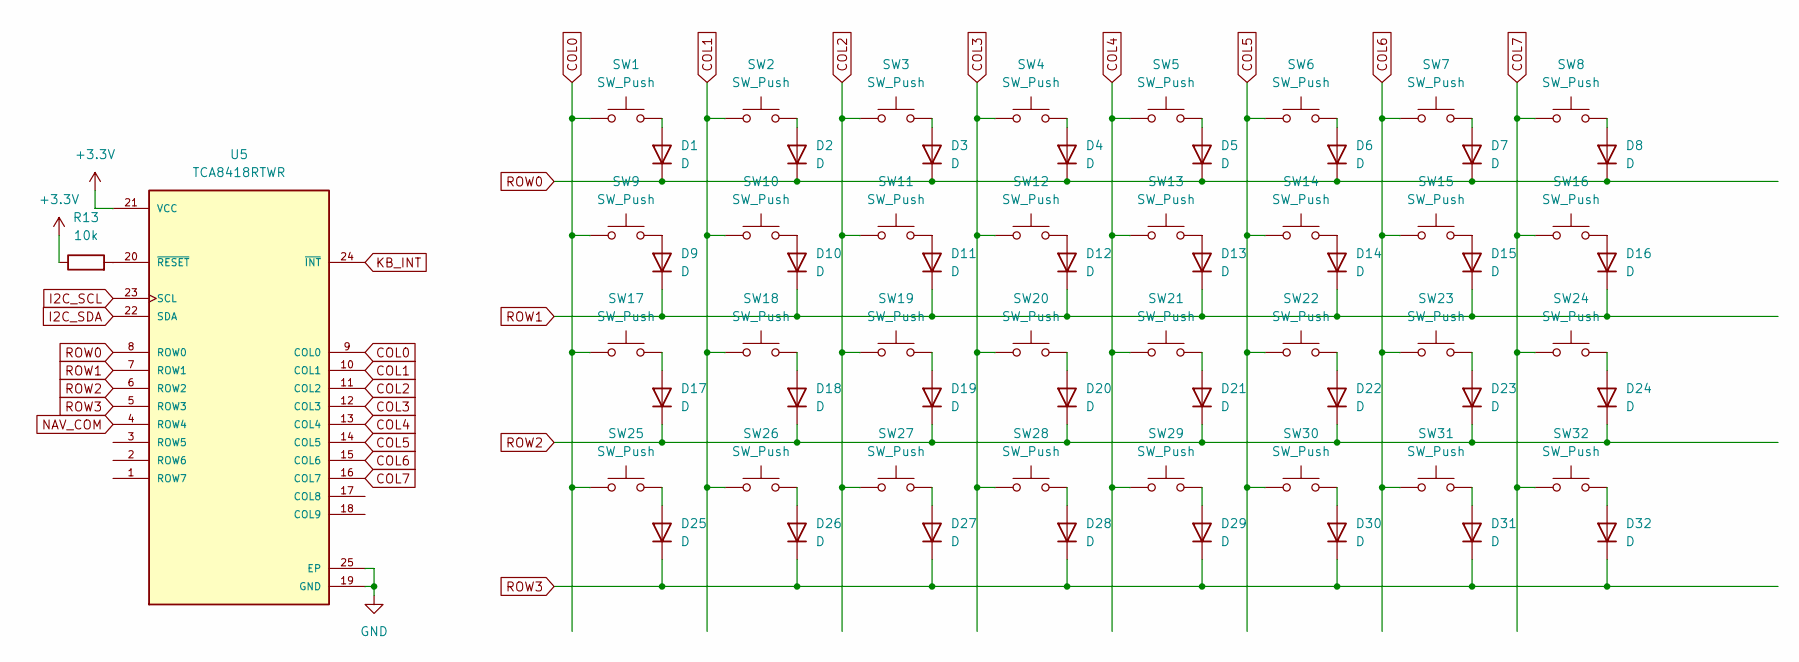
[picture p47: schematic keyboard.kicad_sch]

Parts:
D1, D2, D3, D4, D5, D6, D7, D8, D9, D10, D11, D12, D13, D14, D15, D16, D17, D18, D19, D20, D21, D22, D23, D24, D25, D26, D27, D28, D29, D30, D31, D32: D; D_DO-35_SOD27_P2.54mm_Vertical_KathodeUp
R13: 10k; R_0805_2012Metric_Pad1.20x1.40mm_HandSolder
SW1, SW2, SW3, SW4, SW5, SW6, SW7, SW8, SW9, SW10, SW11, SW12, SW13, SW14, SW15, SW16, SW17, SW18, SW19, SW20, SW21, SW22, SW23, SW24, SW25, SW26, SW27, SW28, SW29, SW30, SW31, SW32: SW_Push; SW_choc_v1_1u
U5: TCA8418RTWR; PARTREV G

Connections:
+3.3V: R13.1, U5.21 (VCC); also elsewhere on the board
COL0: SW1.1, SW9.1, SW17.1, SW25.1, U5.9 (COL0); also elsewhere on the board
COL1: SW2.1, SW10.1, SW18.1, SW26.1, U5.10 (COL1); also elsewhere on the board
COL2: SW3.1, SW11.1, SW19.1, SW27.1, U5.11 (COL2); also elsewhere on the board
COL3: SW4.1, SW12.1, SW20.1, SW28.1, U5.12 (COL3); also elsewhere on the board
COL4: SW5.1, SW13.1, SW21.1, SW29.1, U5.13 (COL4); also elsewhere on the board
COL5: SW6.1, SW14.1, SW22.1, SW30.1, U5.14 (COL5)
COL6: SW7.1, SW15.1, SW23.1, SW31.1, U5.15 (COL6)
COL7: SW8.1, SW16.1, SW24.1, SW32.1, U5.16 (COL7)
GND: U5.19 (GND), U5.25 (EP); also elsewhere on the board
I2C_SCL: U5.23 (SCL); also elsewhere on the board
I2C_SDA: U5.22 (SDA); also elsewhere on the board
KB_INT: U5.24 (~INT); also elsewhere on the board
NAV_COM: U5.4 (ROW4); also elsewhere on the board
unnamed: D1.2 (A), SW1.2
unnamed: D2.2 (A), SW2.2
unnamed: D3.2 (A), SW3.2
unnamed: D4.2 (A), SW4.2
unnamed: D5.2 (A), SW5.2
unnamed: D6.2 (A), SW6.2
unnamed: D7.2 (A), SW7.2
unnamed: D8.2 (A), SW8.2
unnamed: D9.2 (A), SW9.2
unnamed: D10.2 (A), SW10.2
unnamed: D11.2 (A), SW11.2
unnamed: D12.2 (A), SW12.2
unnamed: D13.2 (A), SW13.2
unnamed: D14.2 (A), SW14.2
unnamed: D15.2 (A), SW15.2
unnamed: D16.2 (A), SW16.2
unnamed: D17.2 (A), SW17.2
unnamed: D18.2 (A), SW18.2
unnamed: D19.2 (A), SW19.2
unnamed: D20.2 (A), SW20.2
unnamed: D21.2 (A), SW21.2
unnamed: D22.2 (A), SW22.2
unnamed: D23.2 (A), SW23.2
unnamed: D24.2 (A), SW24.2
unnamed: D25.2 (A), SW25.2
unnamed: D26.2 (A), SW26.2
unnamed: D27.2 (A), SW27.2
unnamed: D28.2 (A), SW28.2
unnamed: D29.2 (A), SW29.2
unnamed: D30.2 (A), SW30.2
unnamed: D31.2 (A), SW31.2
unnamed: D32.2 (A), SW32.2
unnamed: R13.2, U5.20 (~RESET)
ROW0: D1.1 (K), D2.1 (K), D3.1 (K), D4.1 (K), D5.1 (K), D6.1 (K), D7.1 (K), D8.1 (K), U5.8 (ROW0)
ROW1: D9.1 (K), D10.1 (K), D11.1 (K), D12.1 (K), D13.1 (K), D14.1 (K), D15.1 (K), D16.1 (K), U5.7 (ROW1)
ROW2: D17.1 (K), D18.1 (K), D19.1 (K), D20.1 (K), D21.1 (K), D22.1 (K), D23.1 (K), D24.1 (K), U5.6 (ROW2)
ROW3: D25.1 (K), D26.1 (K), D27.1 (K), D28.1 (K), D29.1 (K), D30.1 (K), D31.1 (K), D32.1 (K), U5.5 (ROW3)

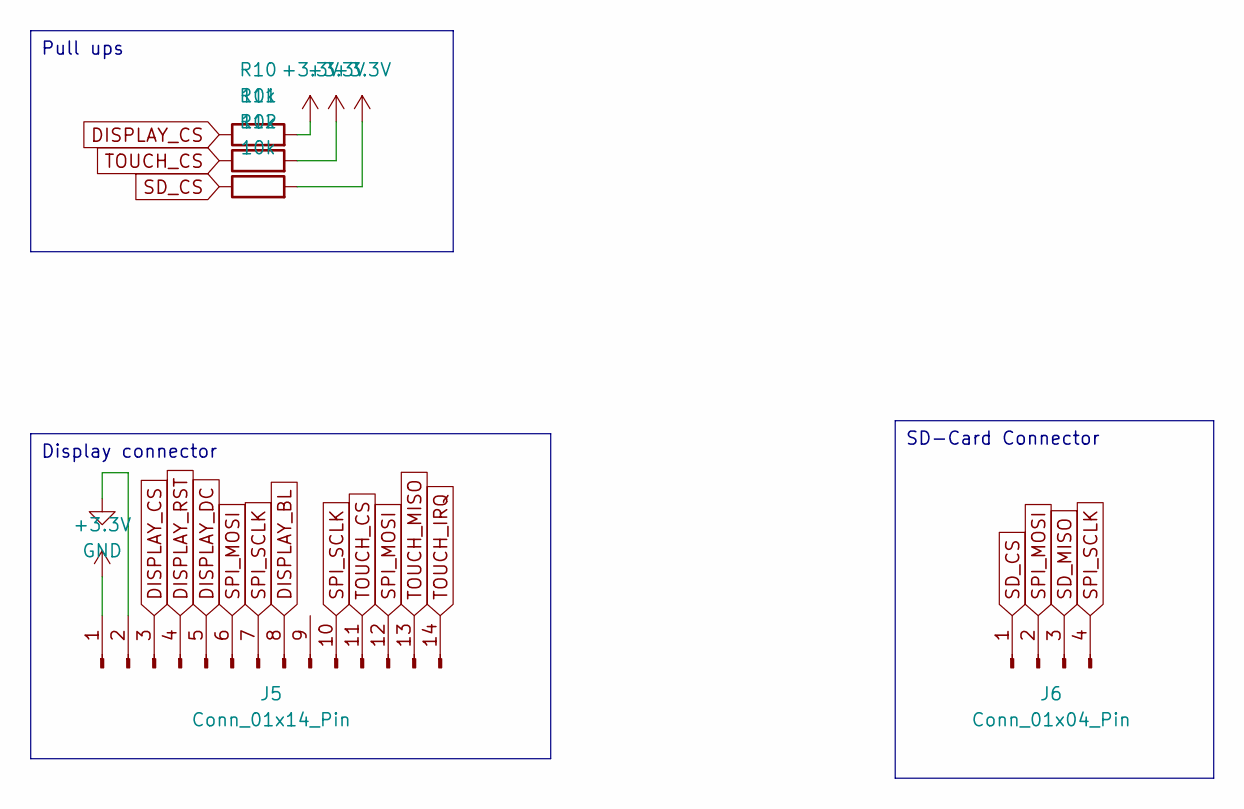
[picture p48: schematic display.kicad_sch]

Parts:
J5: Conn_01x14_Pin; PinSocket_1x14_P2.54mm_Vertical
J6: Conn_01x04_Pin; PinSocket_1x04_P2.54mm_Vertical
R10, R11, R12: 10k; R_0805_2012Metric_Pad1.20x1.40mm_HandSolder

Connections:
+3.3V: J5.1, R10.2, R11.2, R12.2; also elsewhere on the board
DISPLAY_BL: J5.8; also elsewhere on the board
DISPLAY_CS: J5.3, R10.1; also elsewhere on the board
DISPLAY_DC: J5.5; also elsewhere on the board
DISPLAY_RST: J5.4; also elsewhere on the board
GND: J5.2; also elsewhere on the board
SD_CS: J6.1, R12.1; also elsewhere on the board
SD_MISO: J6.3; also elsewhere on the board
SPI_MOSI: J5.6, J5.12, J6.2; also elsewhere on the board
SPI_SCLK: J5.7, J5.10, J6.4; also elsewhere on the board
TOUCH_CS: J5.11, R11.1; also elsewhere on the board
TOUCH_IRQ: J5.14; also elsewhere on the board
TOUCH_MISO: J5.13; also elsewhere on the board

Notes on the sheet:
SD-Card Connector
Display connector
Pull ups

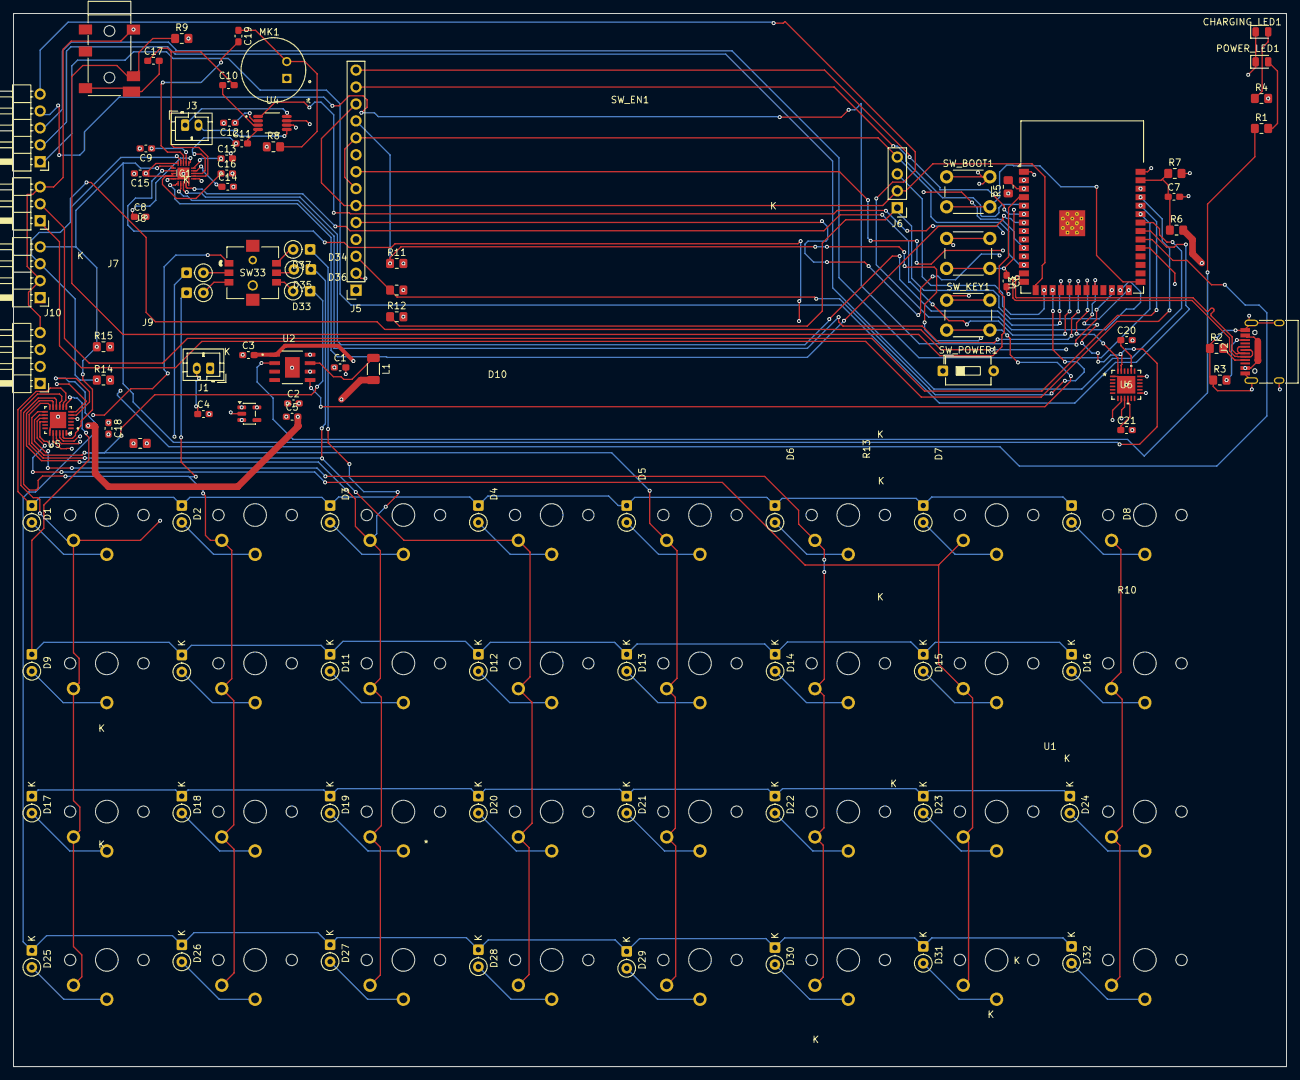
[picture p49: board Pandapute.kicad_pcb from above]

Board: 4 copper layers, 191.0 x 158.0 mm, 131 parts (0 on the bottom side), 113 nets.

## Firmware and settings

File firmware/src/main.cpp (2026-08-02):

#include <Arduino.h>
#include <SPI.h>
#include <TFT_eSPI.h>
#include "config.h"
#include "kernel.h"
#include "keyboard/keyboard.h"
#include "keyboard/keymap.h"
#include "audio/audio.h"
#include "power/power.h"
#include "touch/touch.h"
#include "sd_card/sd_card.h"
#include "usb_hid/usb_hid.h"
#include "mpu/mpu.h"

TFT_eSPI tft;
Keyboard g_keyboard;
Audio g_audio;
PowerManager g_power;
Touch g_touch;
SDCard g_sd;
HIDKeyboard g_hid;
MPU6050 g_mpu;

static unsigned long _last_battery_check = 0;
static uint8_t _hid_mod = 0;

static void _set_modifier(uint8_t keycode, bool on) {
    uint8_t bit = 0;
    if (keycode == KEY_LSHIFT || keycode == KEY_RSHIFT) bit = 0x02;
    else if (keycode == KEY_LCTRL || keycode == KEY_RCTRL) bit = 0x04;
    else if (keycode == KEY_LALT || keycode == KEY_RALT) bit = 0x08;

    if (bit) {
        if (on) _hid_mod |= bit;
        else _hid_mod &= ~bit;
    }
}

static void splash() {
    tft.fillScreen(TFT_BLACK);
    tft.setTextColor(TFT_WHITE, TFT_BLACK);
    tft.setTextSize(3);
    int x = (tft.width() - tft.textWidth("Pandapute v1")) / 2;
    int y = (tft.height() - tft.fontHeight()) / 2;
    tft.setCursor(x, y);
    tft.print("Pandapute v1");
}

void setup() {
    Serial.begin(115200);
    delay(500);

    Serial.println("Pandapute v1");
    Serial.println("Booting...");

    SPI.begin(DISPLAY_SCLK_PIN, SPI_MISO_PIN, DISPLAY_MOSI_PIN, -1);

    tft.init();
    tft.setRotation(1);
    tft.fillScreen(TFT_BLACK);
    pinMode(DISPLAY_BL_PIN, OUTPUT);
    analogWrite(DISPLAY_BL_PIN, 200);
    splash();

    g_keyboard.begin();

    if (g_touch.begin()) Serial.println("Touch: ok");

    if (g_sd.begin())
        Serial.printf("SD: %llu MB\n", g_sd.total_bytes() / (1024 * 1024));

    if (g_audio.begin()) g_audio.play_tone(440, 150);

    g_power.begin();

    if (g_mpu.begin()) Serial.println("MPU: ok");

    g_hid.begin();

    kernel_init();
    kernel_set_status("Ready");
}

void loop() {
    unsigned long now = millis();

    g_keyboard.scan();
    for (int r = 0; r < KEYBOARD_ROWS; r++) {
        for (int c = 0; c < KEYBOARD_COLS; c++) {
            if (g_keyboard.key_just_pressed(r, c)) {
                uint8_t keycode = KEYMAP[r][c];

                _set_modifier(keycode, true);
                if (g_hid.is_connected()) g_hid.send_key(_hid_mod, keycode);
                kernel_key(_hid_mod, keycode);
            }

            if (g_keyboard.key_just_released(r, c)) {
                _set_modifier(KEYMAP[r][c], false);
                if (!g_keyboard.any_key_down()) g_hid.release_all();
            }
        }
    }

    TouchPoint tp = g_touch.read();
    if (tp.valid) {
        Serial.printf("Touch: %d,%d z=%d\n", tp.x, tp.y, tp.z);
    }

    if (now - _last_battery_check > 10000) {
        _last_battery_check = now;
        BatteryStatus bat = g_power.read_battery();
        char buf[24];
        snprintf(buf, sizeof(buf), "Bat: %d%%", bat.level_percent);
        kernel_set_status(buf);
    }

    kernel_tick();

    static unsigned long last_status = 0;
    if (now - last_status > 200) {
        last_status = now;
        kernel_draw_status_bar();
    }

    delay(KEYBOARD_POLL_MS);
}

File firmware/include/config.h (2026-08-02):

#pragma once

// Display (ILI9341 320x240, SPI)
#define DISPLAY_WIDTH          320
#define DISPLAY_HEIGHT         240
#define DISPLAY_MOSI_PIN       13
#define DISPLAY_SCLK_PIN       12
#define DISPLAY_CS_PIN         10
#define DISPLAY_DC_PIN         11
#define DISPLAY_RST_PIN        14
#define DISPLAY_BL_PIN         15

// Touch (XPT2046, shared SPI bus)
#define TOUCH_CS_PIN           21
#define TOUCH_IRQ_PIN          16

// SD card (shared SPI bus)
#define SD_CS_PIN              7
#define SPI_MISO_PIN           9

// Audio (I2S + ES8311 codec)
#define I2S_BCLK_PIN           17
#define I2S_LRCK_PIN           18
#define I2S_DIN_PIN            19
#define I2S_DOUT_PIN           20
#define I2S_MCLK_PIN           6
#define AUDIO_I2C_SDA_PIN      5
#define AUDIO_I2C_SCL_PIN      4
#define ES8311_I2C_ADDR        0x18

// Power (IP5306)
#define IP5306_I2C_ADDR        0x75
#define POWER_LED_PIN          48
#define CHARGING_LED_PIN       47
#define BAT_ADC_PIN            1
#define BAT_ADC_DIVIDER_R1     100000.0f
#define BAT_ADC_DIVIDER_R2     100000.0f

// Keyboard matrix (direct GPIO scan)
#define KEYBOARD_ROWS          4
#define KEYBOARD_COLS          8
static const uint8_t MATRIX_ROW_PINS[KEYBOARD_ROWS] = {26, 27, 28, 29};
static const uint8_t MATRIX_COL_PINS[KEYBOARD_COLS] = {30, 31, 32, 33, 34, 35, 36, 37};

// Keyboard controller (on-board, not used by firmware)
#define TCA8418_I2C_ADDR       0x34

// USB (native)
#define USB_D_PLUS_PIN         23
#define USB_D_MINUS_PIN        22

// UART
#define UART_TX_PIN            43
#define UART_RX_PIN            44

// Navigation
#define NAV_COM_PIN            45

// System
#define DEBOUNCE_THRESHOLD_MS  5
#define KEYBOARD_POLL_MS       10
#define STATUS_BAR_HEIGHT      20

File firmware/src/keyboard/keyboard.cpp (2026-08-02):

#include "keyboard.h"
#include "config.h"
#include <Arduino.h>

Keyboard::Keyboard() {
    memset(_raw_matrix, 0, sizeof(_raw_matrix));
    memset(_debounced_matrix, 0, sizeof(_debounced_matrix));
    memset(_previous_matrix, 0, sizeof(_previous_matrix));
    memset(_debounce_counters, 0, sizeof(_debounce_counters));
    _last_scan_us = 0;
}

void Keyboard::begin() {
    for (int c = 0; c < KEYBOARD_COLS; c++) {
        pinMode(MATRIX_COL_PINS[c], INPUT_PULLUP);
    }
    for (int r = 0; r < KEYBOARD_ROWS; r++) {
        pinMode(MATRIX_ROW_PINS[r], OUTPUT);
        digitalWrite(MATRIX_ROW_PINS[r], HIGH);
    }
}

void Keyboard::_deselect_all_rows() {
    for (int r = 0; r < KEYBOARD_ROWS; r++) {
        digitalWrite(MATRIX_ROW_PINS[r], HIGH);
    }
    delayMicroseconds(5);
}

void Keyboard::_select_row(uint8_t row) {
    digitalWrite(MATRIX_ROW_PINS[row], LOW);
    delayMicroseconds(5);
}

void Keyboard::_read_columns(uint8_t row) {
    for (int c = 0; c < KEYBOARD_COLS; c++) {
        _raw_matrix[row][c] = (digitalRead(MATRIX_COL_PINS[c]) == LOW) ? 1 : 0;
    }
}

void Keyboard::scan() {
    unsigned long now = micros();
    if (now - _last_scan_us < 1000) return;
    _last_scan_us = now;

    memcpy(_previous_matrix, _debounced_matrix, sizeof(_previous_matrix));

    for (int r = 0; r < KEYBOARD_ROWS; r++) {
        _deselect_all_rows();
        _select_row(r);
        _read_columns(r);
    }
    _deselect_all_rows();

    for (int r = 0; r < KEYBOARD_ROWS; r++) {
        for (int c = 0; c < KEYBOARD_COLS; c++) {
            uint8_t current = _raw_matrix[r][c];
            if (current == _debounced_matrix[r][c]) {
                _debounce_counters[r][c] = 0;
            } else {
                _debounce_counters[r][c]++;
                if (_debounce_counters[r][c] >= DEBOUNCE_THRESHOLD_MS) {
                    _debounced_matrix[r][c] = current;
                    _debounce_counters[r][c] = 0;
                }
            }
        }
    }
}

bool Keyboard::key_down(uint8_t row, uint8_t col) const {
    if (row >= KEYBOARD_ROWS || col >= KEYBOARD_COLS) return false;
    return _debounced_matrix[row][col];
}

bool Keyboard::key_just_pressed(uint8_t row, uint8_t col) const {
    if (row >= KEYBOARD_ROWS || col >= KEYBOARD_COLS) return false;
    return _debounced_matrix[row][col] && !_previous_matrix[row][col];
}

bool Keyboard::key_just_released(uint8_t row, uint8_t col) const {
    if (row >= KEYBOARD_ROWS || col >= KEYBOARD_COLS) return false;
    return !_debounced_matrix[row][col] && _previous_matrix[row][col];
}

bool Keyboard::any_key_down() const {
    for (int r = 0; r < KEYBOARD_ROWS; r++)
        for (int c = 0; c < KEYBOARD_COLS; c++)
            if (_debounced_matrix[r][c]) return true;
    return false;
}

const uint8_t (&Keyboard::debounced_matrix() const)[KEYBOARD_ROWS][KEYBOARD_COLS] {
    return _debounced_matrix;
}

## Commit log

2026-07-24 adding PCB 3D model screenshots for visualization
    [BOM.csv, Pandapute.kicad_pcb]
2026-07-24 added the 3D Model in to new folder called CAD, also updated README with Case plans
2026-07-26 added Case step Files
    [CaseBottom.step, CaseTop.step, Pandapute.kicad_pcb]
2026-07-26 updated README and JOURNAL with Case entries
2026-07-26 BOm dollar conversion
    [BOM.csv]
